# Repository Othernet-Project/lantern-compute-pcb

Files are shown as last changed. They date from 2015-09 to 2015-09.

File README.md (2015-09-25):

# lantern-compute-pcb
The files in this repo pertain to Lantern's main PCB. This includes the schematic, gerbers, and BOM, in addition to project outputs from Altrium 15. 

Lantern is a portable satellite data receiver which consists of a main compute board and separate RF module which receives satellite transmissions between 1525MHz and 1559MHz. 

V1 of the Lantern compute pcb is derived from the Beaglebone Black single board computer. The main differences between V1 and BBB include the addition of a DVB-S2 network interface module (NIM), as well as an onboard wifi module. Unlike the BBB, V1 does not provide for a video interface.

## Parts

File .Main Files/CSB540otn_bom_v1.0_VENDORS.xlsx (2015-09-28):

Comment | Description | Designator | Footprint | LibRef | Quantity | Vendor | Manufacturer | Mfg Part Number
22PF_50V, 0402 | CAP - 0402 PKG | C1, C2, C3, C4, C35, C36, C130, C140 | 0402C | 22PF_50V, 0402 | 8 | Digikey | KEMET | C0402C220J5GACTU
10UF_10V, 0805 | CAP - 0805 PKG | C5, C32, C47, C50, C56, C59, C61, C62, C116, C126, C128, C134, C155 | 0805C | 10UF_10V, 0805 | 13 | Digikey | TAIYO YUDEN | LMK212F106ZG-T
2.2UF_6V, 0402 | CAP - 0402 PKG | C6, C7, C8, C9, C10, C11, C12, C18, C23, C25, C26, C38, C51, C55, C67, C72, C77, C82, C87, C92, C97, C102, C112, C139, C141, C145, C147, C149, C150 | 0402C | 2.2UF_6V, 0402 | 29 | Digikey | TAIYO YUDEN | JMK105BJ225MV-F
0.1UF_16V, 0402 | CAP - 0402 PKG | C13, C14, C15, C16, C17, C19, C20, C21, C22, C24, C30, C31, C33, C37, C39, C40, C41, C42, C43, C52, C53, C54, C63, C64, C65, C66, C68, C69, C70, C71, C73, C74, C75, C76, C78, C79, C80, C81, C83, C84, C85, C86, C88, C89, C90, C91, C93, C94, C95, C96, C98, C99, C100, C101, C107, C108, C109, C110, C111, C122, C129, C142, C143, C144, C146, C148, C151, C152 | 0402C | 0.1UF_16V, 0402 | 68 | Digikey | TAIYO YUDEN | EMK105B7104KV-F
10UF_6V, 0603 | CAP - 0603 PKG | C27, C28, C124, C132 | 0603C | 10UF_6V, 0603 | 4 | Digikey | SAMSUNG | CL10A106MQ8NNNC
1000PF_2KV, 1206 | CAP - 1206 PKG | C29 | 1206C | 1000PF_2KV, 1206 | 1 | Digikey | KEMET | C1206C102KGRACTU
220UF_16V_POLY_8X8 | CAP - ELEC_POLY, 8mm x 8mm x 3.5mm | C34, C46, C58, C117, C118, C153 | ELEC_8MM_8MM | 220UF_16V_POLY_8X8 | 6 | Digikey | NICHICON | RL81C221MDN1KX
1UF_10V, 0402 | CAP - 0402 PKG | C44, C49, C103, C104, C105, C113, C114, C115, C123, C138, C154, C156 | 0402C | 1UF_10V, 0402 | 12 | Digikey | MURATA | GRM155R61A105KE15D
0PF_DNP, 0402 | CAP - 0402 PKG | C45, C57, C125, C131 | 0402C | 0PF_DNP, 0402 | 4
22UF_6V, 0805 | CAP - 0805 PKG | C48, C60, C121, C127, C133 | 0805C | 22UF_6V, 0805 | 5 | Digikey | TAIYO YUDEN | JMK212BJ226MG-T
.01UF_25V, 0402 | CAP - 0402 PKG | C106, C120 | 0402C | .01UF_25V, 0402 | 2 | Digikey | MURATA | GRM155R71E103KA01D
22UF_10V, 1206 | CAP - 1206 PKG | C119 | 1206C | 22UF_10V, 1206 | 1 | Digikey | TAIYO YUDEN | LMK316F226ZL-T
22UF_25V, 1210 | CAP - 1210 PKG | C135 | 1210C | 22UF_25V, 1210 | 1 | Digikey | TAIYO YUDEN | TMK325BJ226MM-T
220UF_35V, ELEC_8X11.5 | CAP - ELEC, 8mm x 11.5mm x 3.5mm | C136 | ELEC_8MM_11.5MM | 220UF_35V, ELEC_8X11.5 | 1 | Digikey | NICHICON | UVY1V221MPD
2200PF_50V, 0402 | CAP - 0402 PKG | C137 | 0402C | 2200PF_50V, 0402 | 1 | Digikey | TAIYO YUDEN | UMK105B7222KV-F
LED_1X3_SIDE-YELLOW | LED - SIDEVIEW, SMT, YELLOW | D1, D18 | LED_1X3_SIDE-YELLOW | LED_1X3_SIDE-YELLOW | 2 | Digikey | KINGBRIGHT | APA3010SYCK-GX
SEMTECH_RCLAMP0524PA | DIODE - TVS ARRAY, 0.3PF | D2, D10 | RCLAMP0524 | SEMTECH_RCLAMP0524PA | 2 | Digikey | SEMTECH | RCLAMP0524PATCT
LED_1X3_SIDE-GREEN | LED - SIDEVIEW, SMT, GREEN | D3, D7, D8 | LED_1X3_SIDE-GREEN | LED_1X3_SIDE-GREEN | 3 | Digikey | LITE-ON | LTST-S326KGJSKT
BAT54C, SOT-23 | DIODE - DUAL SCHOTTKY, COMMON CATHODE, 30V, 200MA | D4, D9 | SOT-23 | BAT54C, SOT-23 | 2 | Digikey | DIODES INC | BAT54C-7-F
BAT60, SOD-323 | DIODE - POWER, SCHOTTKY, 10V, 3A | D5 | SOD-323 | BAT60, SOD-323 | 1 | Digikey | ST Micro | BAT60JFILM
V10PN50, SOT-277 | DIODE - SCHOTTKY, 50V, 10A | D6 | SOT-277 | V10PN50, SOT-277 | 1 | Digikey | VISHAY | V10PN50-M3/86A
LED_1X3_SIDE-RED | LED - SIDEVIEW, SMT, RED | D11 | LED_1X3_SIDE-RED | LED_1X3_SIDE-RED | 1 | Digikey | KINGBRIGHT | APA3010SRCPRV-GX
LED_1X3_SIDE-WHITE | LED - SIDEVIEW, SMT, WHITE | D17 | LED_1X3_SIDE-WHITE | LED_1X3_SIDE-WHITE | 1 | Digikey | DIALIGHT | 5972903507F
MBRA340, SMA | DIODE - POWER, SCHOTTKY, 40V, 3A | D20 | SMA | MBRA340, SMA | 1 | Digikey | ON SEMI | MBRA340T3G
BAT54T, SOT-523 | DIODE - SCHOTTKY, 30V, 200MA | D21 | SOT-523 | BAT54T, SOT-523 | 1 | Digikey | DIODES INC | BAT54T-7-F
FIDUCIAL | MISC - 75mm/35mm FIDUCIAL | FID1, FID2 | FIDUCIAL | FIDUCIAL | 2
CUI_PJ-037BH | CONN - DC JACK, 2.5mm CENTER PLUS, 5 AMP | J1 | CUI_PJ-037B | CUI_PJ-037BH | 1 | Digikey | CUI INC | PJ-037B
SRP4020-1R0M | INDUCTOR - 1.0UH, 5/6A, 4MM x 4MM x 2MM, 22mohm | L2, L4, L10, L11, L17, L18 | SRP4020 | SRP4020-1R0M | 6 | Digikey | BOURNS | SRP4020-1R0M
FERRITE_600, 0402 | FERRITE BEAD - 600 OHM, 300MA, 0402 PKG | L5, L6, L7 | 0402L | FERRITE_600, 0402 | 3 | Digikey | TAIYO YUDEN | BK1005HS601-T
MURATA_DLP11TB800UL2 | FERRITE - COMMON MODE FILTER, USB3, FILM | L8, L19, L20 | PANASONIC_EXC24C | MURATA_DLP11TB800UL2 | 3 | Digikey | MURATA | DLP11TB800UL2L
FERRITE_600, 0805 | FERRITE BEAD - 600 OHM, 2A, 0805 PKG | L9, L13, L14, L15, L16, L23 | 0805L | FERRITE_600, 0805 | 6 | Digikey | TDK CORP | MMZ2012R601A
MURATA_DLP11SA900HL2 | FERRITE - COMMON MODE FILTER, USB2/HDMI/GIGe, FILM | L12 | PANASONIC_EXC24C | MURATA_DLP11SA900HL2 | 1 | Digikey | MURATA | DLP11SA900HL2L
NRS5020T-100M | INDUCTOR - 10UH, 1.3A/1.45A, 5MM x 5MM x 2MM | L22 | NRS5020T | NRS5020T-100M | 1 | Digikey | TAIYO YUDEN | NRS5020T100MMGJ
MTG_M2.5_UNPLATED | MTG HOLE - 2.75mm HOLE 2-56 OR M2.5 | M1, M2, M3, M4 | MTG_M2.5_UNPLATED | MTG_M2.5_UNPLATED | 4
HANRUN_HR851150H | CONN - RJ45 10/100 W/POE, SPEEDTECH | P1 | SPEEDTECH_P65-101-1HQ9 | HANRUN_HR851150H | 1 | HANRUN | HANRUN | HR851150H
USB-A-SMT | CONN - USB TYPE A SMT | P2 | USB-A-SMT | USB-A-SMT | 1 | Digikey | FCI | 87583-2010BLF
USB-MICRO-B | CONN - USB TYPE B MICRO | P3 | USB-MICRO-B | USB-MICRO-B | 1 | Digikey | FCI | 10118193-0001lf
USB-A-DUAL | CONN - USB TYPE A - DUAL | P4 | USB-A-DUAL | USB-A-DUAL | 1 | Digikey | FCI | 72309-8034BLF
HDR2 - NOPOP | HEADER - 2-PIN, HOLES ONLY FOR WIRE | P5, P7 | HDR2X1-NOPOP | HDR2 - NOPOP | 2
ARM-ICE, HDR20 | CONN - ARM JTAG CONNECTOR | P6 | HDR20 | ARM-ICE, HDR20 | 1 | Digikey | ON SHORE TECH | 302-S201
2N7002T, SOT-523 | N-FET - 60V, 500ma @ 10V, Vgs(th) 2V | Q1, Q3, Q5 | SOT-523 | 2N7002T, SOT-523 | 3 | Digikey | DIODES INC | 2N7002T-7-F
FDMA910PZ, MICROFET-22 | P-FET - 20V, 7.2A @ 1.8Vgs, 34mohm | Q2, Q4 | MICROFET-22 | FDMA910PZ, MICROFET-22 | 2 | Digikey | FAIRCHILD SEMI | FDMA910PZ
2N7002V, SOT-563 | N-FET - DUAL, 60V, 500ma @ 10V, Vgs(th) 2V | Q6 | SOT-563 | 2N7002V, SOT-563 | 1 | Digikey | DIODES INC | 2N7002V-7
1K, 0402 | RES - 0402 PKG | R1, R6, R46, R47, R48, R53, R56 | 0402R | 1K, 0402 | 7 | Digikey | VISHAY | CRCW04021K00JNED
2.2K, 0402 | RES - 0402 PKG | R2, R54 | 0402R | 2.2K, 0402 | 2 | Digikey | VISHAY | CRCW04022K20JNED
10K, 0402 | RES - 0402 PKG | R3, R15, R16, R20, R23, R24, R30, R31, R38, R42, R52, R57, R58, R60, R61 | 0402R | 10K, 0402 | 15 | Digikey | VISHAY | CRCW040210K0JNED
49.9_1%, 0402 | RES - 0402 PKG | R4 | 0402R | 49.9_1%, 0402 | 1 | Digikey | VISHAY | CRCW040249R9FKED
240, 0402 | RES - 0402 PKG | R5 | 0402R | 240, 0402 | 1 | Digikey | VISHAY | CRCW0402240RJNED
33, 0402 | RES - 0402 PKG | R7, R8, R32, R50 | 0402R | 33, 0402 | 4 | Digikey | VISHAY | CRCW040233R0JNED
1.00K_1%, 0402 | RES - 0402 PKG | R9, R10, R65 | 0402R | 1.00K_1%, 0402 | 3 | Digikey | VISHAY | CRCW04021K00FKED
12.1K_1%, 0402 | RES - 0402 PKG | R11 | 0402R | 12.1K_1%, 0402 | 1 | Digikey | VISHAY | CRCW040212K1FKED
10.0K_1%, 0402 | RES - 0402 PKG | R12, R29, R37, R41, R44, R59 | 0402R | 10.0K_1%, 0402 | 6 | Digikey | VISHAY | CRCW040210K0FKED
75, 0402 | RES - 0402 PKG | R13, R27, R35, R49 | 0402R | 75, 0402 | 4 | Digikey | VISHAY | CRCW040275R0JNED
1M, 0402 | RES - 0402 PKG | R14, R34 | 0402R | 1M, 0402 | 2 | Digikey | VISHAY | CRCW04021M00JNED
330, 0402 | RES - 0402 PKG | R17, R18, R19 | 0402R | 330, 0402 | 3 | Digikey | VISHAY | CRCW0402330RFKED
475K_1%, 0402 | RES - 0402 PKG | R21 | 0402R | 475K_1%, 0402 | 1 | Digikey | VISHAY | CRCW0402475KFKED
1.1K, 0402 | RES - 0402 PKG | R22 | 0402R | 1.1K, 0402 | 1 | Digikey | VISHAY | CRCW04021K10JNED
16.9K_1%, 0402 | RES - 0402 PKG | R25 | 0402R | 16.9K_1%, 0402 | 1 | Digikey | VISHAY | CRCW040216K9FKED
0_DNP, 0402 | RES - 0402 PKG, DO NOT POPULATE BY DEFAULT | R26, R33, R39, R43 | 0402R | 0_DNP, 0402 | 4
12.7K_1%, 0402 | RES - 0402 PKG | R28 | 0402R | 12.7K_1%, 0402 | 1 | Digikey | VISHAY | CRCW040212K7FKED
31.6K_1%, 0402 | RES - 0402 PKG | R36 | 0402R | 31.6K_1%, 0402 | 1 | Digikey | VISHAY | CRCW040231K6FKED
3.92K_1%, 0402 | RES - 0402 PKG | R40 | 0402R | 3.92K_1%, 0402 | 1 | Digikey | VISHAY | CRCW04023K92FKED
14.3K_1%, 0402 | RES - 0402 PKG | R45 | 0402R | 14.3K_1%, 0402 | 1 | Digikey | VISHAY | CRCW040214K3FKED
100K, 0402 | RES - 0402 PKG | R51, R62, R63 | 0402R | 100K, 0402 | 3 | Digikey | VISHAY | CRCW0402100KJNED
12.0K_1%, 0402 | RES - 0402 PKG | R55 | 0402R | 12.0K_1%, 0402 | 1 | Digikey | VISHAY | CRCW040212K0FKED
2.67K_1%, 0402 | RES - 0402 PKG | R64 | 0402R | 2.67K_1%, 0402 | 1 | Digikey | VISHAY | CRCW04022K67FKED
10KNI, EXB-28V | RES NET, 4 INDIVIDUAL, EXB-28V | RN1, RN3, RN4, RN8, RN9, RN10, RN11, RN12, RN13, RN14, RN17, RN18, RN19, RN20 | EXB-28V | 10KNI, EXB-28V | 14 | Digikey | PANASONIC | EXB-28V103JX
36NI, EXB-28V | RES NET, 4 INDIVIDUAL, EXB-28V | RN2, RN5, RN6, RN7, RN15, RN16 | EXB-28V | 36NI, EXB-28V | 6 | Digikey | PANASONIC | EXB-28V360JX
MOLEX_104031-0811 | CONN - SD/MMC, MICRO, PUSH/PUSH, W/CD | SD1 | MOLEX_104031-0811 | MOLEX_104031-0811 | 1 | Digikey | MOLEX | 104031-0811
ALP_SKQM | SWITCH - PUSHBUTTON SMT, 6MM X 3.5MM | SW1, SW4 | ALPS_SKQM | ALP_SKQM | 2 | MOUSER | ALPS | SKQMASE010
KSS221G | SWITCH - PUSHBUTTON SMT, SIDE ACTUATED | SW2, SW3 | KSS221G | KSS221G | 2 | Digikey | C&K COMPONENTS | KSS221GLFS
DDR3_TESTPOINTS_X16 | MISC - DDR3 ROUTING PATTERN, 16-BIT | TP1 | DDR2-TP | DDR3_TESTPOINTS_X16 | 1
TP20R | MISC - TEST PAD, 20MIL ROUND | TP2, TP3 | TP_20R | TP20R | 2
SMAJ5CA, SMA | DIODE - TVS, 6.4V MIN., 7.25V MAX. | TVS1 | SMA | SMAJ5CA, SMA | 1 | Digikey | LITTELFUSE INC | SMAJ5.0CA
AM3358BZCZA100 | MPU - CORTEX-A8 CORE, SDIO, GIGe, USB x2, UART x3, CAN, 2D/3D | U1 | BGA324x18 | AM3358BZCZA100 | 1 | Digikey | TEXAS INSTRUMENTS | AM3358BZCZA100
AP2141, SOT-25-5 | IC - POWER SWITCH, 500MA, LOW TRUE | U3 | SOT-23-5 | AP2141, SOT-23-5 | 1 | Digikey | DIODES, INC | AP2141WG-7
MTFC4GACAANA-4M IT, TBGA100 | NAND FLASH - eMMC 4GB/8GB | U4 | TBGA100 | MTFC4GACAANA-4M IT, TBGA100 | 1 | ARROW | MICRON TECH | MTFC4GACAANA-4M IT
MT41K256M16HA-125M:E, BGA96 | SDRAM - 4GBIT, DDR3/L-1600, x16 | U5 | BGA96_DDR3_X16 | MT41K256M16HA-125M:E, BGA96 | 1 | ARROW | MICRON TECH | MT41K256M16HA-125:E
RT9040GQW, DFN10 | LDO - DDR2/3 VREF AND VTT, 3A | U7 | DFN10 | RT9040GQW, DFN10 | 1 | Digikey | RICHTEK USA | RT9040GQW
LAN8720A-CP, QFN24 | PHY - 10/100 RMII | U8 | QFN24 | LAN8720A-CP, QFN24 | 1 | Digikey | MICROCHIP TECH | LAN8720A-CP-TR
TPS3801E18DCK, SC-70-5 | IC - RESET, 1.71V, 200MSEC, MR INPUT, OPEN DRAIN OUTPUT | U9 | SOT-353/SC-70-5 | TPS3801E18DCK, SC-70-5 | 1 | Digikey | TEXAS INSTRUMENTS | TPS3801E18DCKR
FAN5354MPX, MLP12 | SWITCHER - 270ua Iq, 3A, 2.7V TO 5.5V IN, 0.8V TO VIN OUT | U11, U14, U18, U19, U20 | mlp12 | FAN5354MPX, MLP12 | 5 | Digikey | FAIRCHILD SEMI | FAN5354MPX
FSA832L10X, MICROPAK10 | USB - BATTERY CHARGER DETECTION W/SWITCH | U12 | MICROpack10 | FSA832L10X, MICROPAK10 | 1 | Digikey | FAIRCHILD SEMI | FSA832L10X
COSY_TS2M08-HF111 | RF - MODULE, DVB-S2 TUNER/DEMODULATOR | U13 | TS2M08-HFF11 | COSY_TS2M08-HF111 | 1 |  | COSY | TS2M08-HF111
TPS61232DRC, SON10 | SWITCHER - 500ua Iq, BOOST 5A, 2.3V TO 5.5V IN, 2.5V TO 5.5V OUT | U15 | SON10 | TPS61232DRC, SON10 | 1 | Digikey | TEXAS INSTRUMENTS | TPS61232DRCT
CP2104-F03-GM, QFN24 | USB - UART W/4 GPIO | U16 | QFN24 | CP2104-F03-GM, QFN24 | 1 | Digikey | SILICON LABS | CP2104-F03-GM
MCP73123-22S, DFN10 | IC - BATTERY CHARGER, 1 CELL LiFePO4, 1.1 AMAX | U17 | DFN10 | MCP73123-22S, DFN10 | 1 | Digikey | MICROCHIP TECH | MCP73123-22SI/MF
AP2141, SOT-43-5 | IC - POWER SWITCH, 500MA, LOW TRUE | U21 | SOT-23-5 | AP2141, SOT-23-5 | 1 | Digikey | DIODES, INC | AP2141WG-7
MIC94060, SC-70-6 | IC - POWER SWITCH, 1.7V - 5.5V @ 2A, HIGH TRUE | U22, U24, U24 | SOT-363/SC-70-6 | MIC94060, SC-70-6 | 3 | Digikey | MICREL, INC | MIC94060YC6 TR
OGEMRAY_GWF-3M08 | MODULE - WIFI, RALINK RT5370 802.11b/g/n | U23 | OGEMRAY_GWF-3M08-XX-T-2 | OGEMRAY_GWF-3M08 | 1 |  | OGEMRAY | GWF-3M08
USB2514BI-AEZG, QFN36 | USB - 2.0 HUB, FOUR PORT, I-TEMP | U25 | QFN36 | USB2514BI-AEZG, QFN36 | 1 | Digikey | MICROCHIP TECH | USB2514B-AEZC-TR
AP2141, SOT-23-5 | IC - POWER SWITCH, 500MA, LOW TRUE | U26 | SOT-23-5 | AP2141, SOT-23-5 | 1 | Digikey | DIODES, INC | AP2141WG-7
LTC4412, SOT-23-6 | IC - POWER SOURCE SELECTOR | U27 | SOT-23-6 | LTC4412, SOT-23-6 | 1 | Digikey | LINEAR TECH | LTC4412ES6#TRMPBF
LMR64010XMF, SOT-23-5 | SWITCHER - BOOST, 1ma Iq, 2.7V TO 14V IN, VIN TO 40V OUT | U28 | SOT-23-5 | LMR64010XMF, SOT-23-5 | 1 | Digikey | TEXAS INSTRUMENTS | LMR64010XMFE/NOPB
BH18PB1WHFV, SOT-553 | LDO - 4ua Iq, 150ma, 3.4V - 5.5V IN, 1.8V OUT, 600mv Vdrop | VR1 | SOT-553 | BH18PB1WHFV, SOT-553 | 1 | Digikey | ROHM | BH18PB1WHFV-TR
32.768KHZ-12, 1206 | CRYSTAL - SMT, 1206, 12.5PF, ABS07 PKG | X1 | 1206X | 32.768KHZ-12, 1206 | 1 | Digikey | ABRACON | ABS07-32.768KHZ-T
24MHZ, X3225 | CRYSTAL - SMT, 3.2MM x 2.5MM, ABM8 PKG | X2, X4 | X3225 | 24MHZ, X3225 | 2 | Digikey | ABRACON | ABM8-24.000MHZ-B2-T
25MHZ, X3225 | CRYSTAL - SMT, 3.2MM x 2.5MM, ABM8 PKG | X3 | X3225 | 25MHZ, X3225 | 1 | Digikey | ABRACON | ABM8-25.000MHZ-B2-T

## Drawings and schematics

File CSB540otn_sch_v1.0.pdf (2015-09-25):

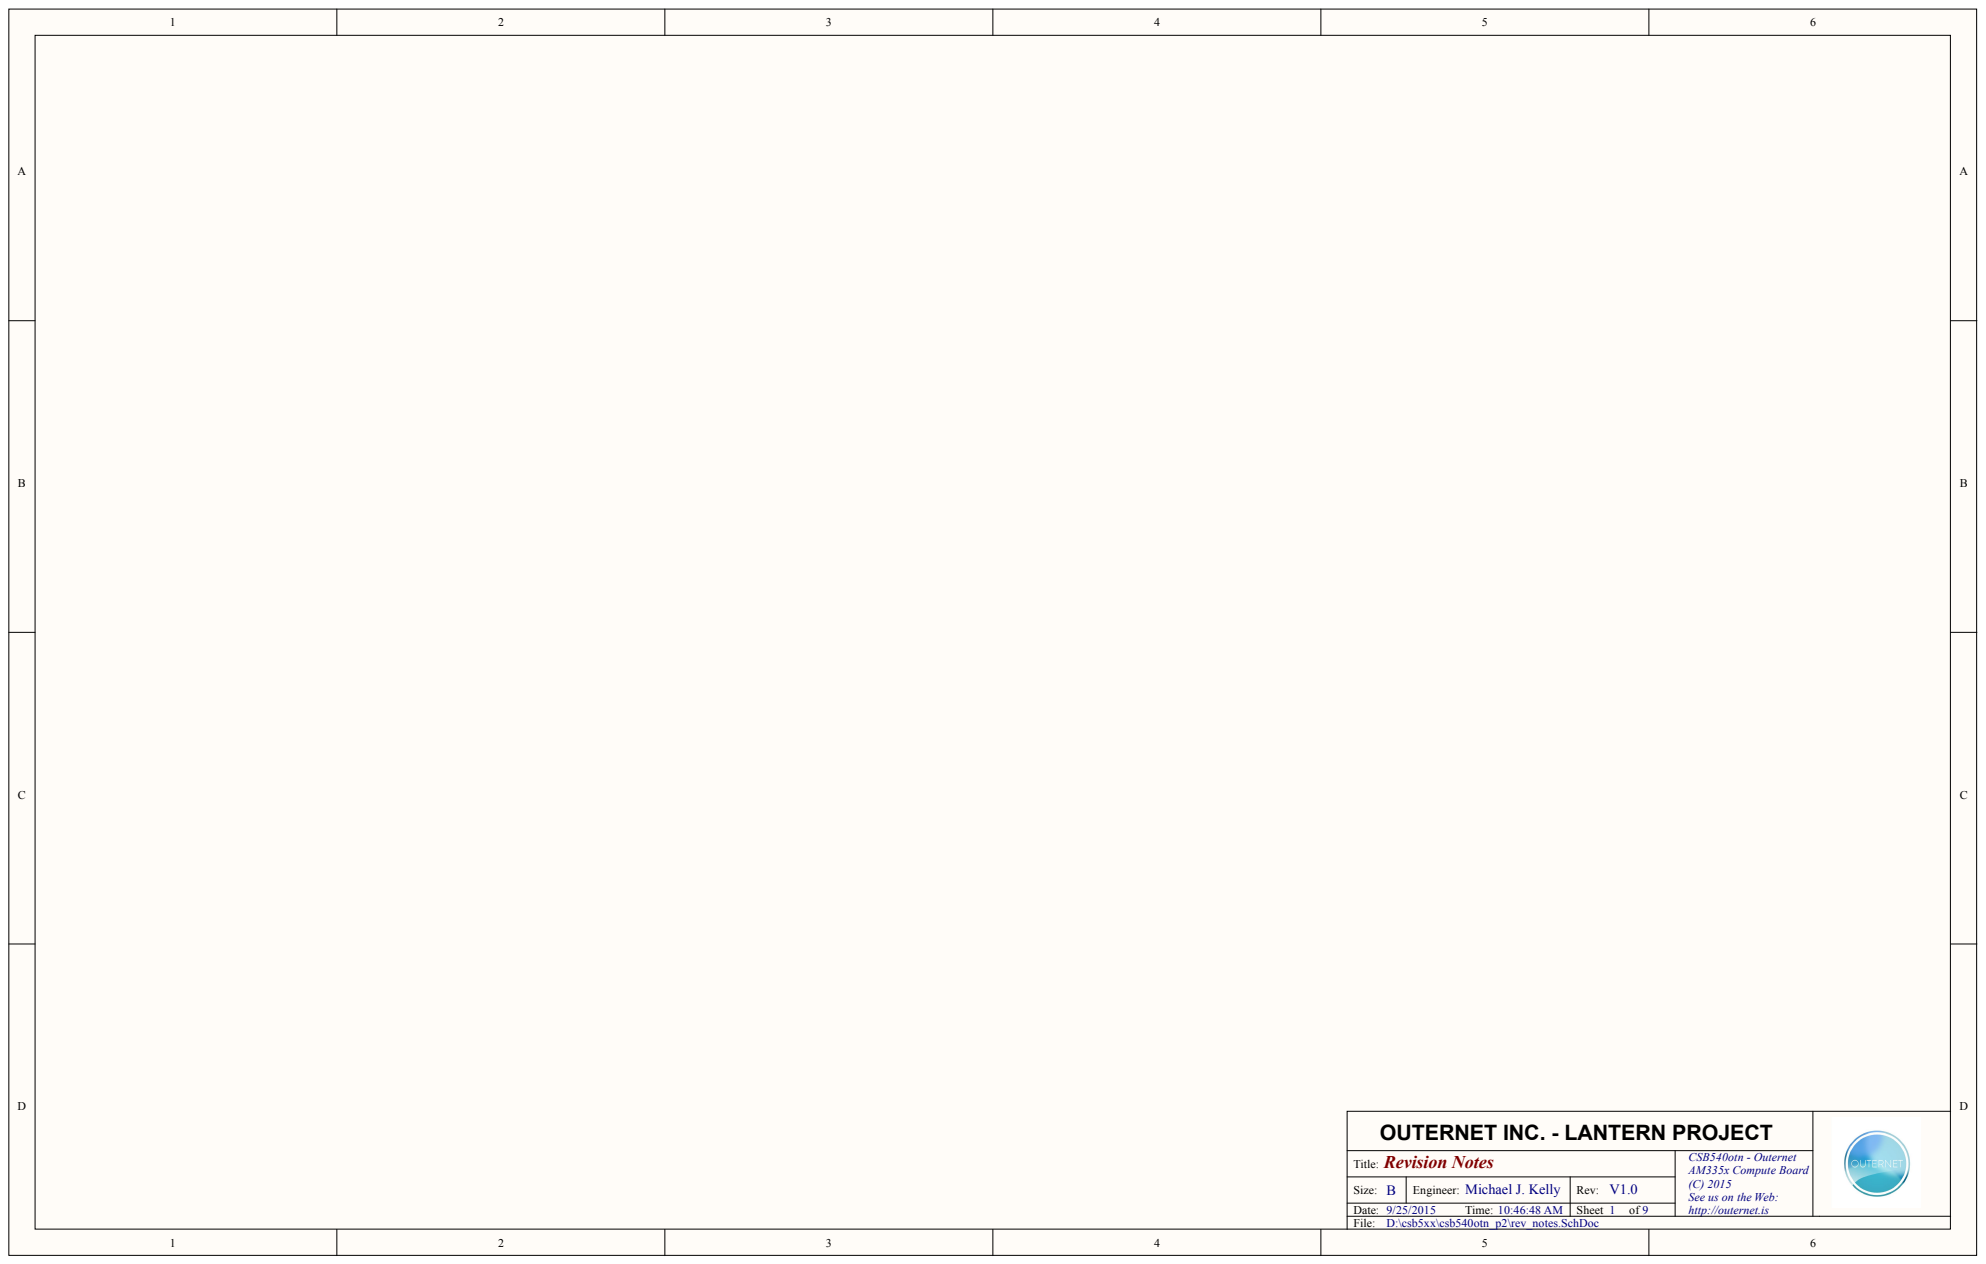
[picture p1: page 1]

OUTERNET INC. - LANTERN PROJECT

Title: Revision Notes | CSB540otn - Outernet AM335x Compute Board (C) 2015 See us on the Web: http://outernet.is

Size: B | Engineer: Michael J. Kelly | Rev: V1.0

Date: 9/25/2015 Time: 10:46:48 AM | | Sheet 1 of 9

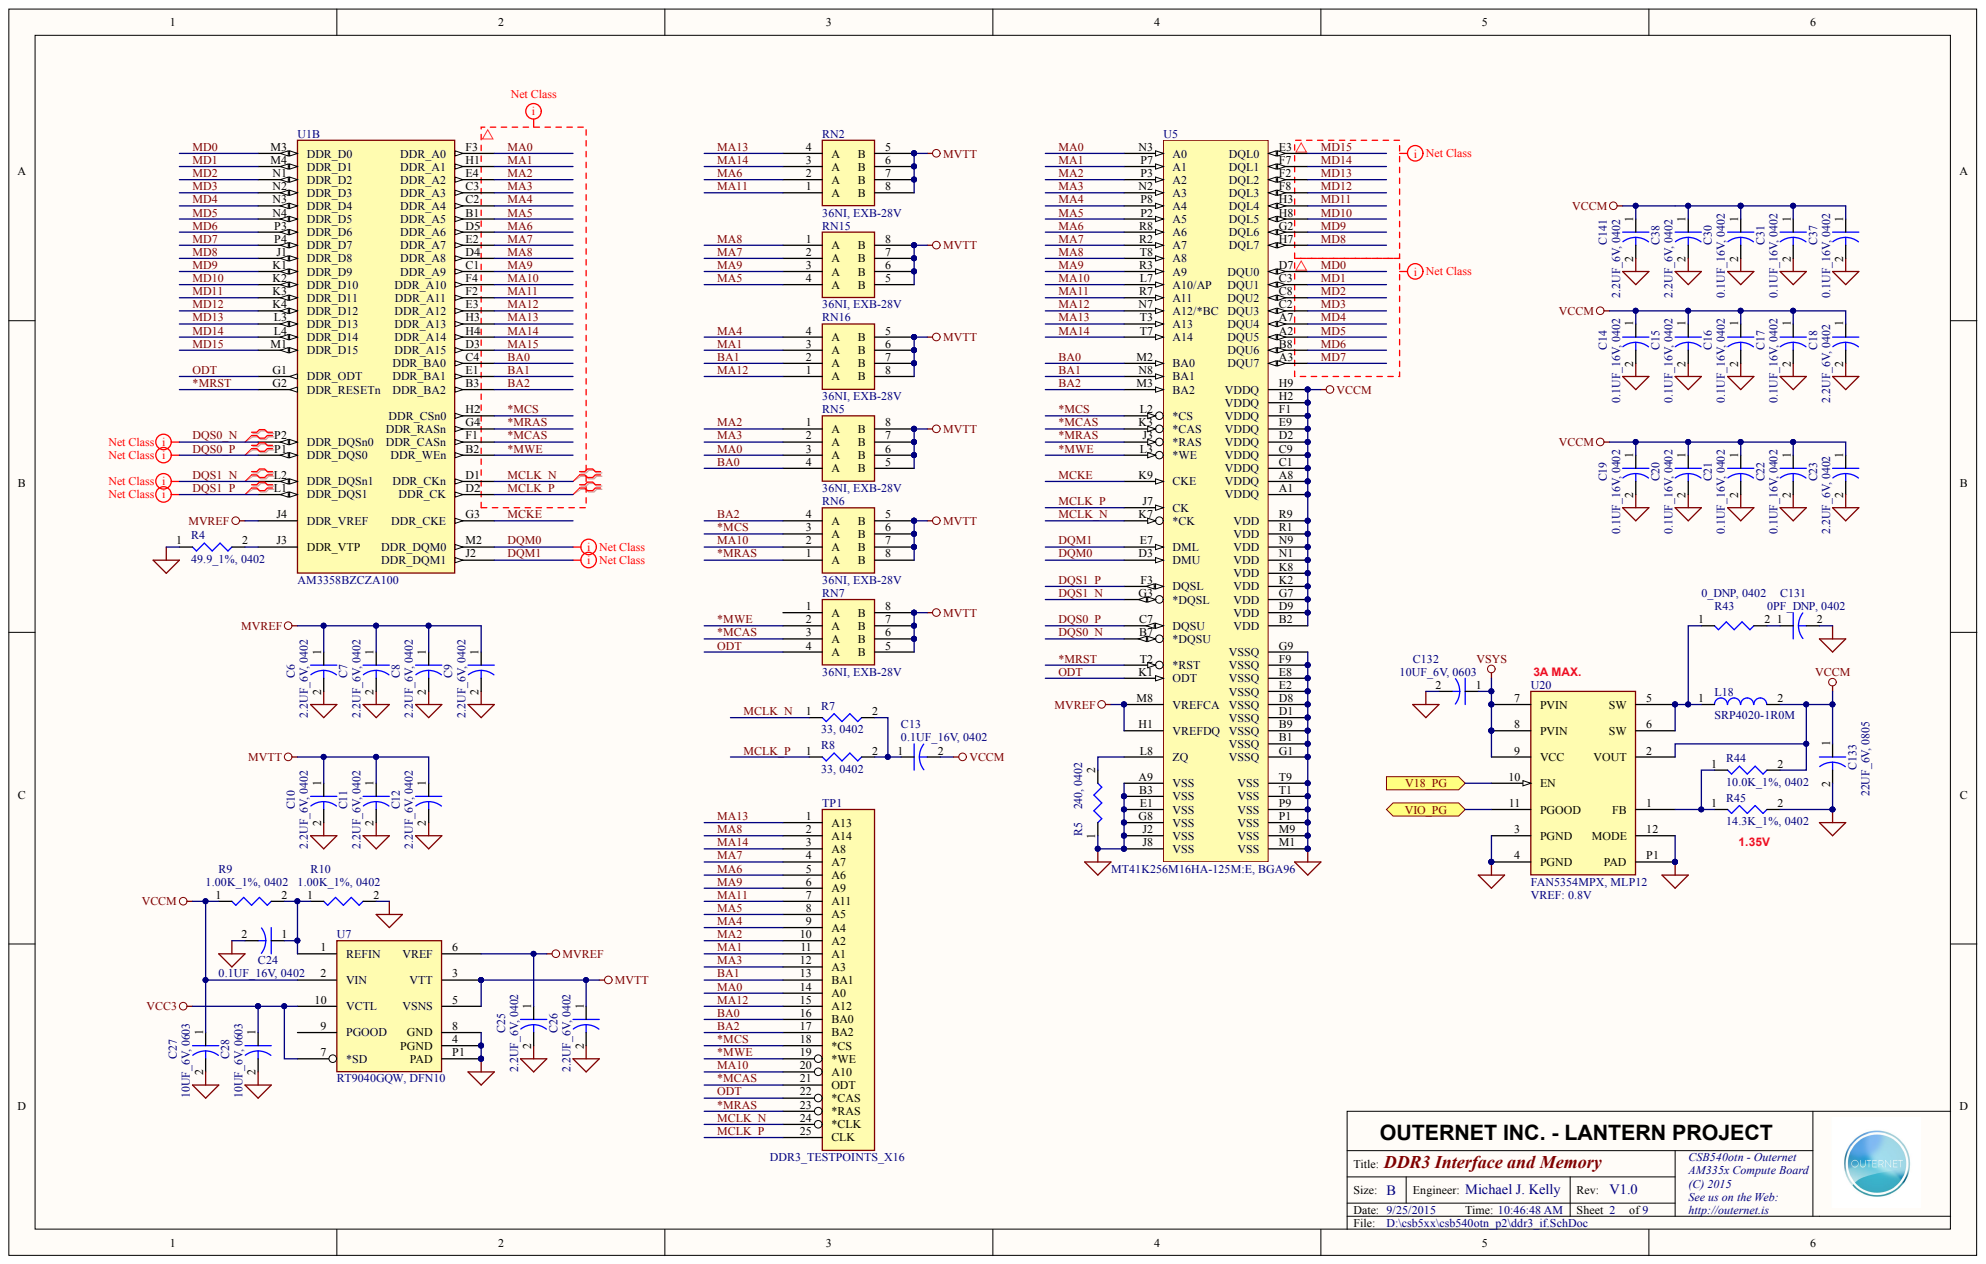
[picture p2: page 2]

i Net Class

OUTERNET INC. - LANTERN PROJECT

Size: B | En gineer: Michael J. Kelly | Rev : V1.0

Date: 9/2 5/2 0 1 5 Time: 1 0:4 6:4 8 AM | | Sheet 2 o f 9

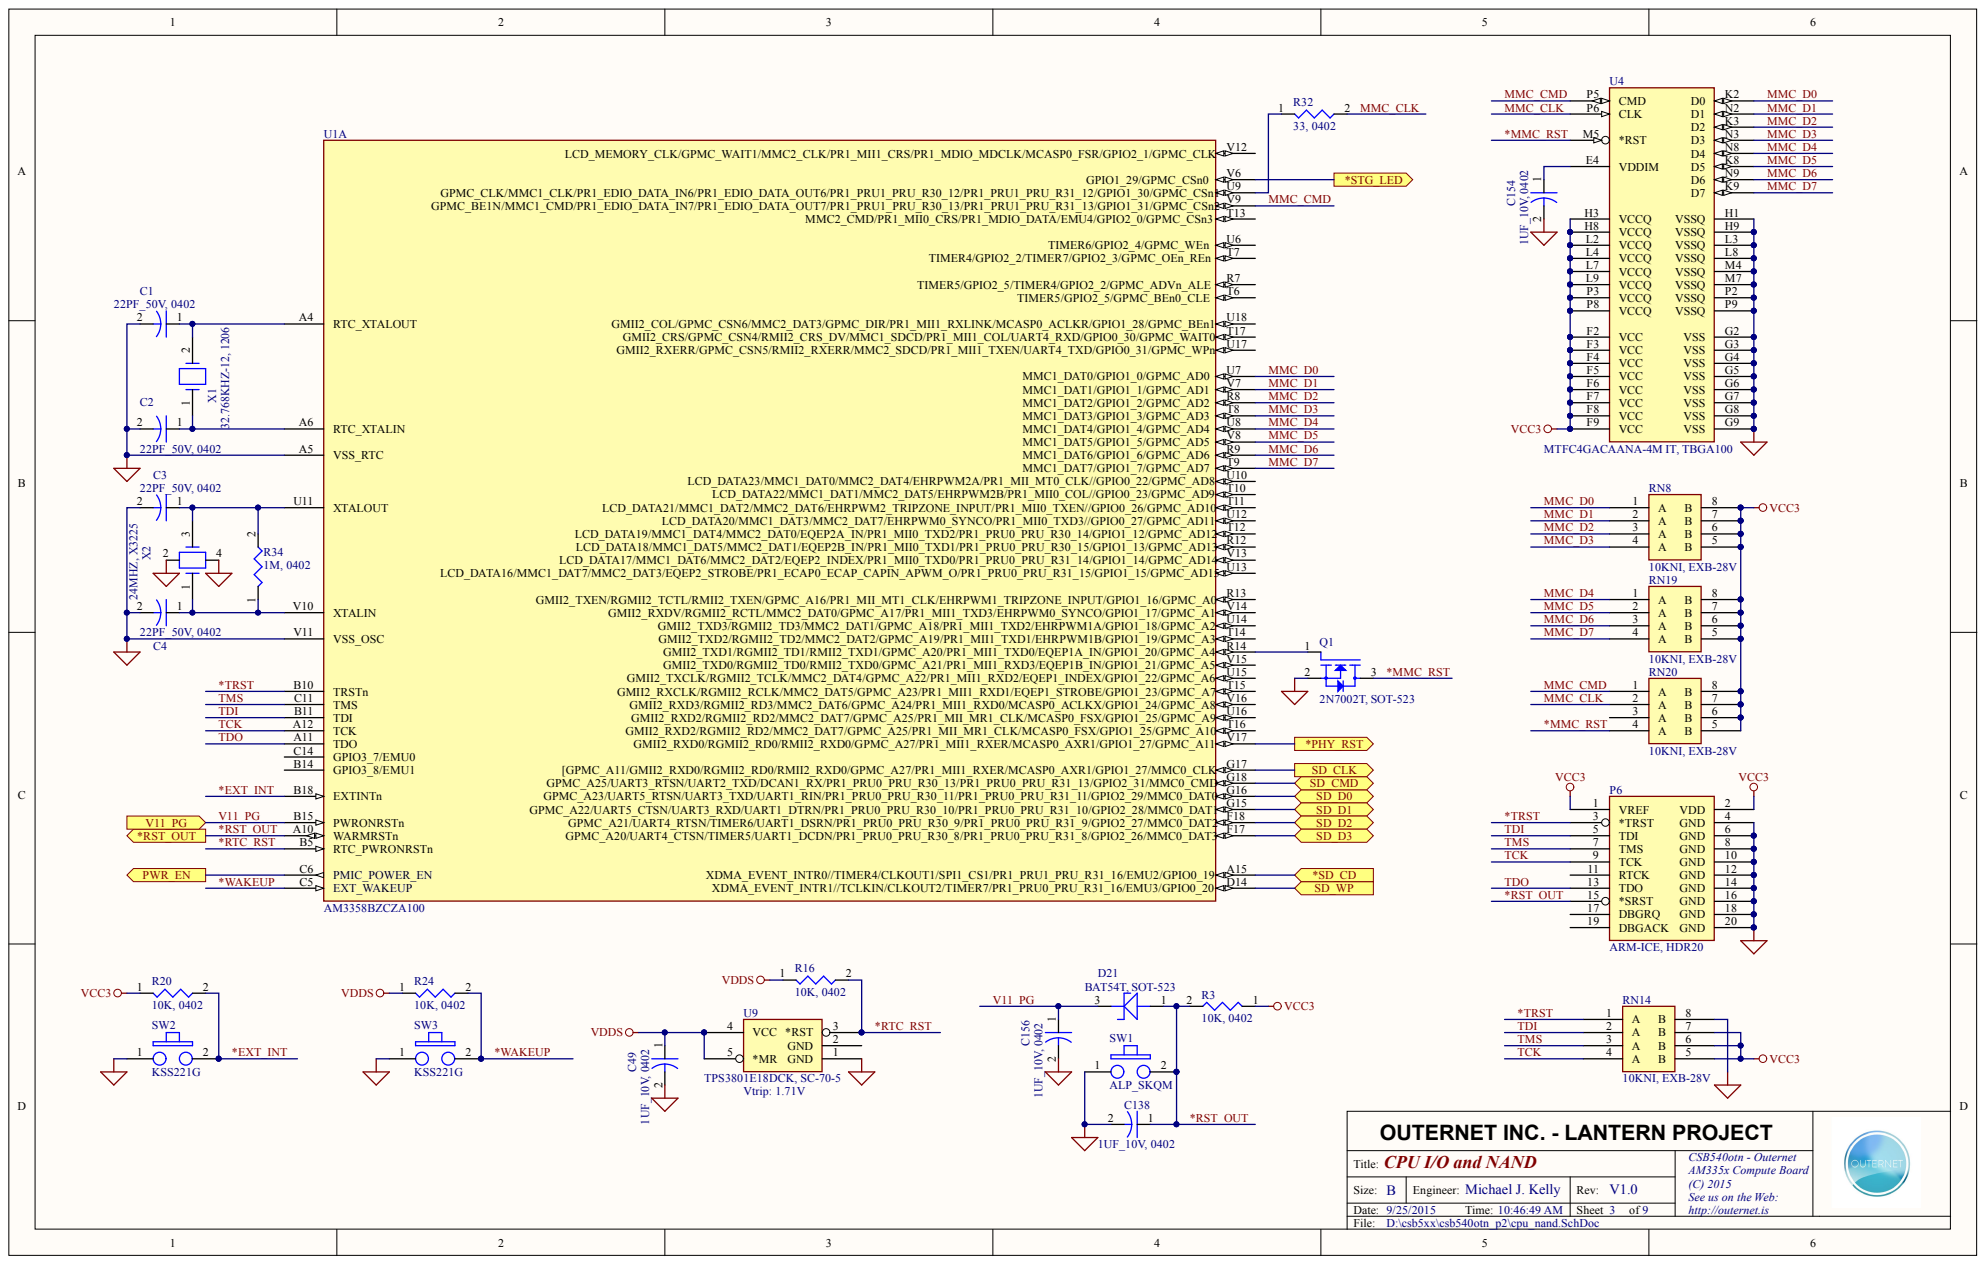
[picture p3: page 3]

OUTERNET INC. - LANTERN PROJECT

Title: CPU I/O and NAND | CSB540otn - Outernet AM335x Compute Board (C) 2015 See us on the Web: http://outernet.is

Size: B | Engineer: Michael J. Kelly | Rev: V1.0

Date: 9/25/2015 Time: 10:46:49 AM | | Sheet 3 of 9

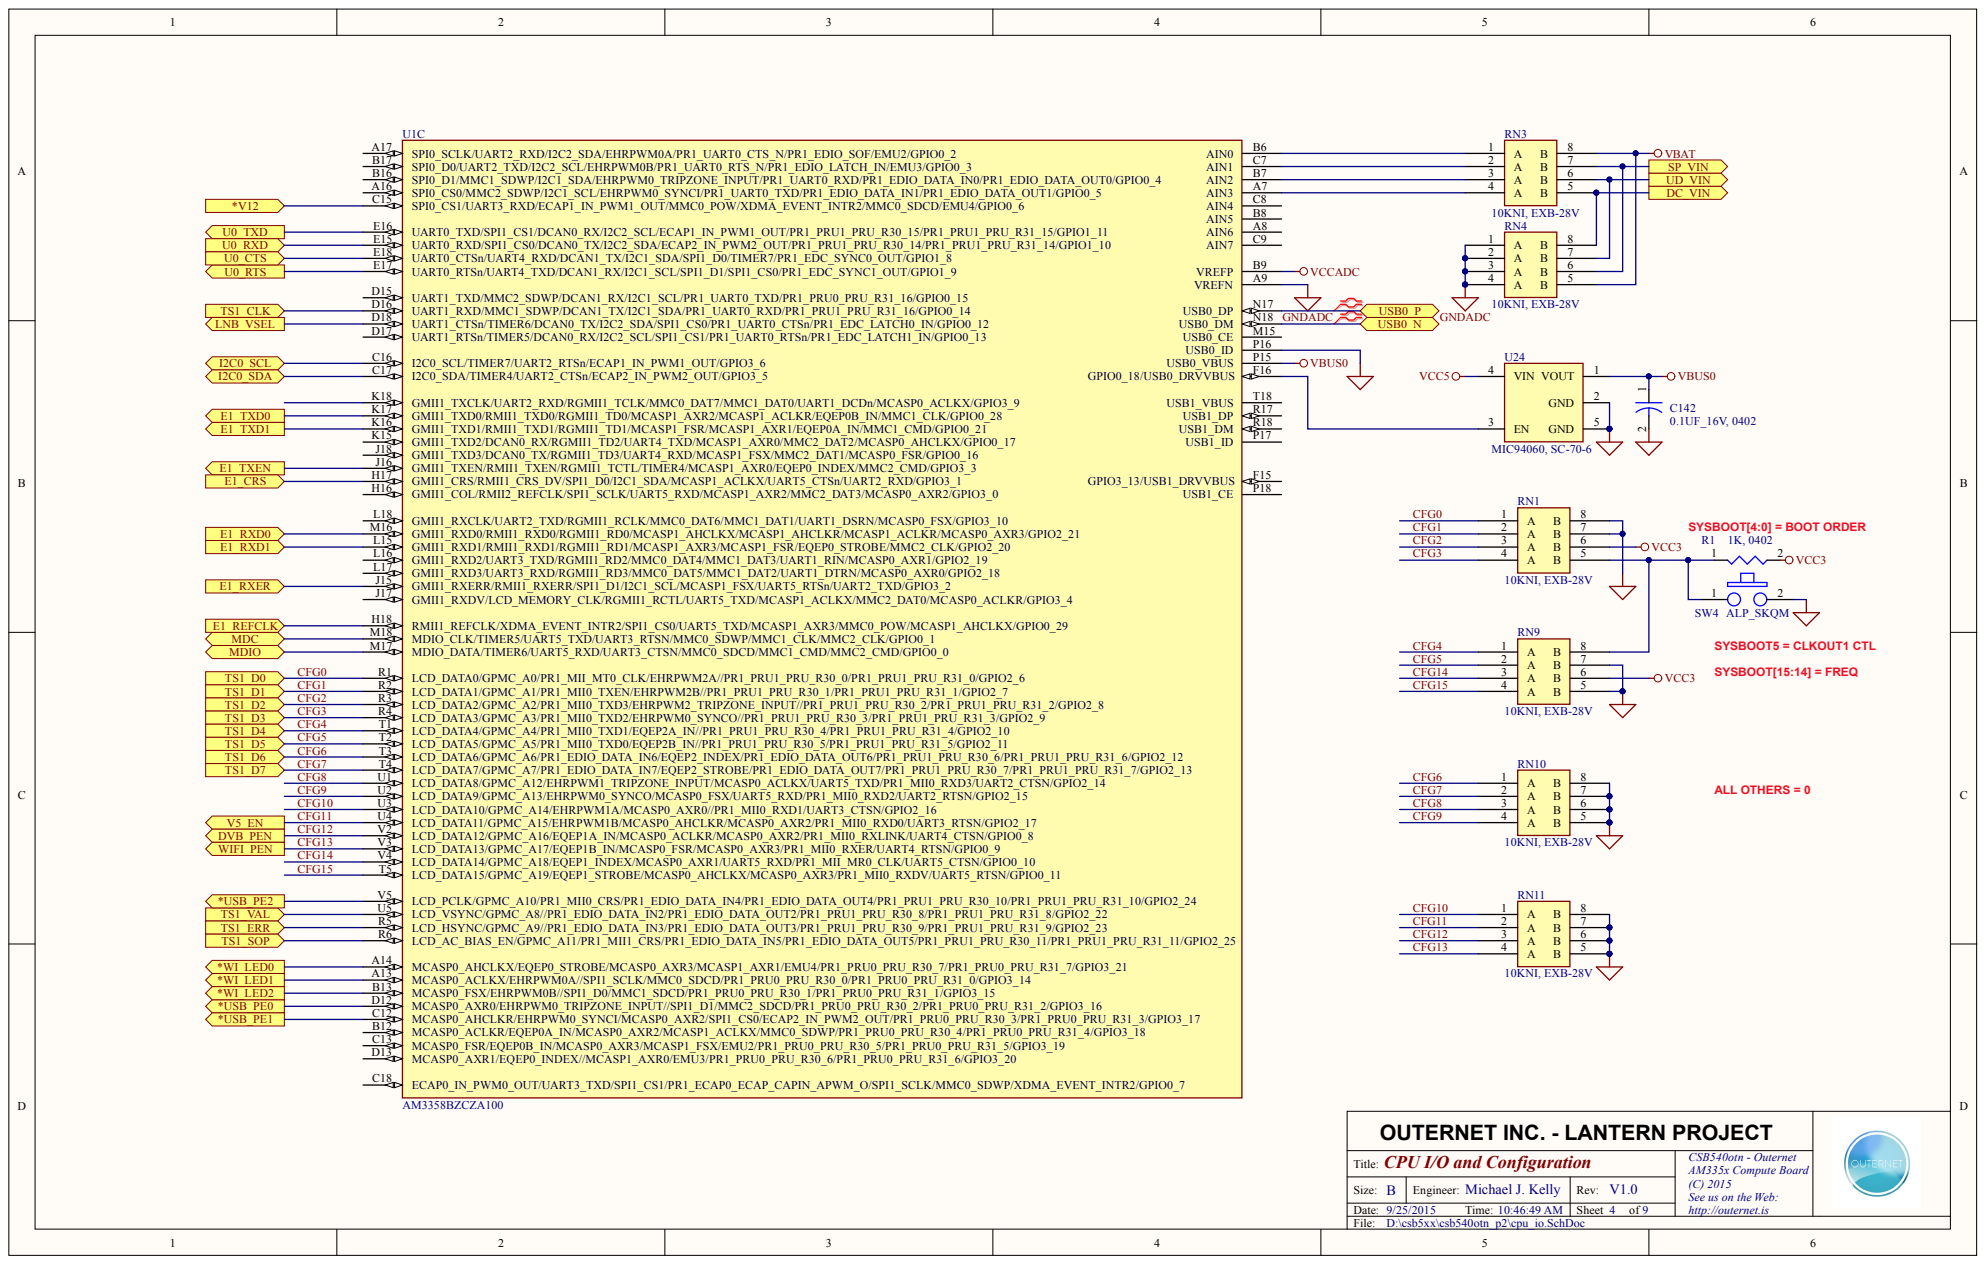
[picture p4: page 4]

1 8 V USB0 _ P USB0 _N

OUTERNET INC. - LANTERN PROJECT

Title: CPU I/O and Configuration | CSB5 4 0 otn - Outernet AM3 3 5x Comp ute Bo a rd (C) 2 0 1 5 See us o n the Web : http://o uternet.is

Size: B | En gineer: Michael J. Kelly | Rev : V1.0

Date: 9/2 5/2 0 1 5 Time: 1 0:4 6:4 9 AM | | Sheet 4 o f 9

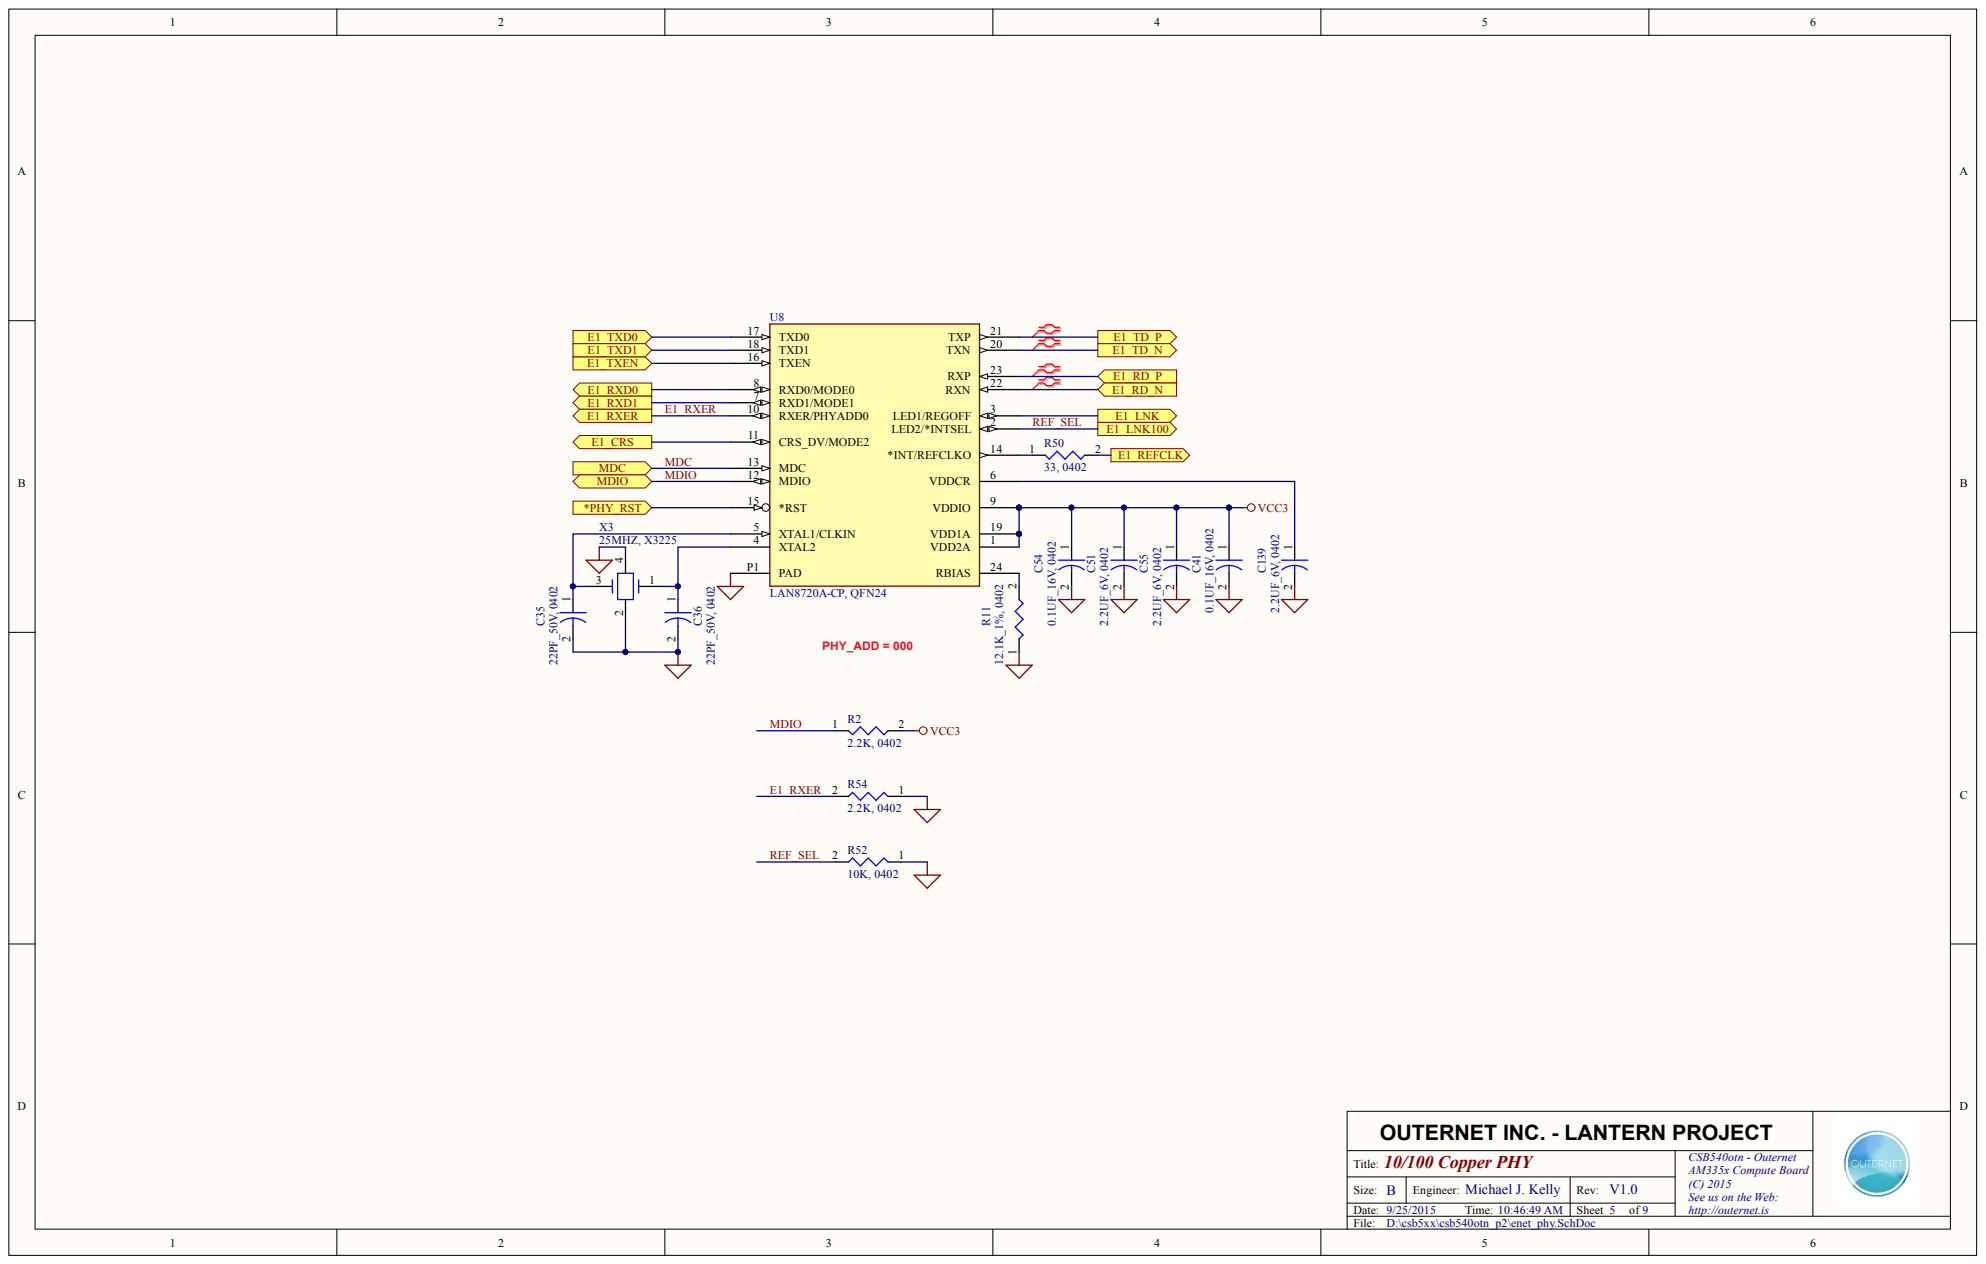
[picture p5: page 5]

OUTERNET INC. - LANTERN PROJECT

Title: 10/100 Copper PHY | CSB540otn - Outernet AM335x Compute Board (C) 2015 See us on the Web: http://outernet.is

Size: B | Engineer: Michael J. Kelly | Rev: V1.0

Date: 9/25/2015 Time: 10:46:49 AM | | Sheet 5 of 9

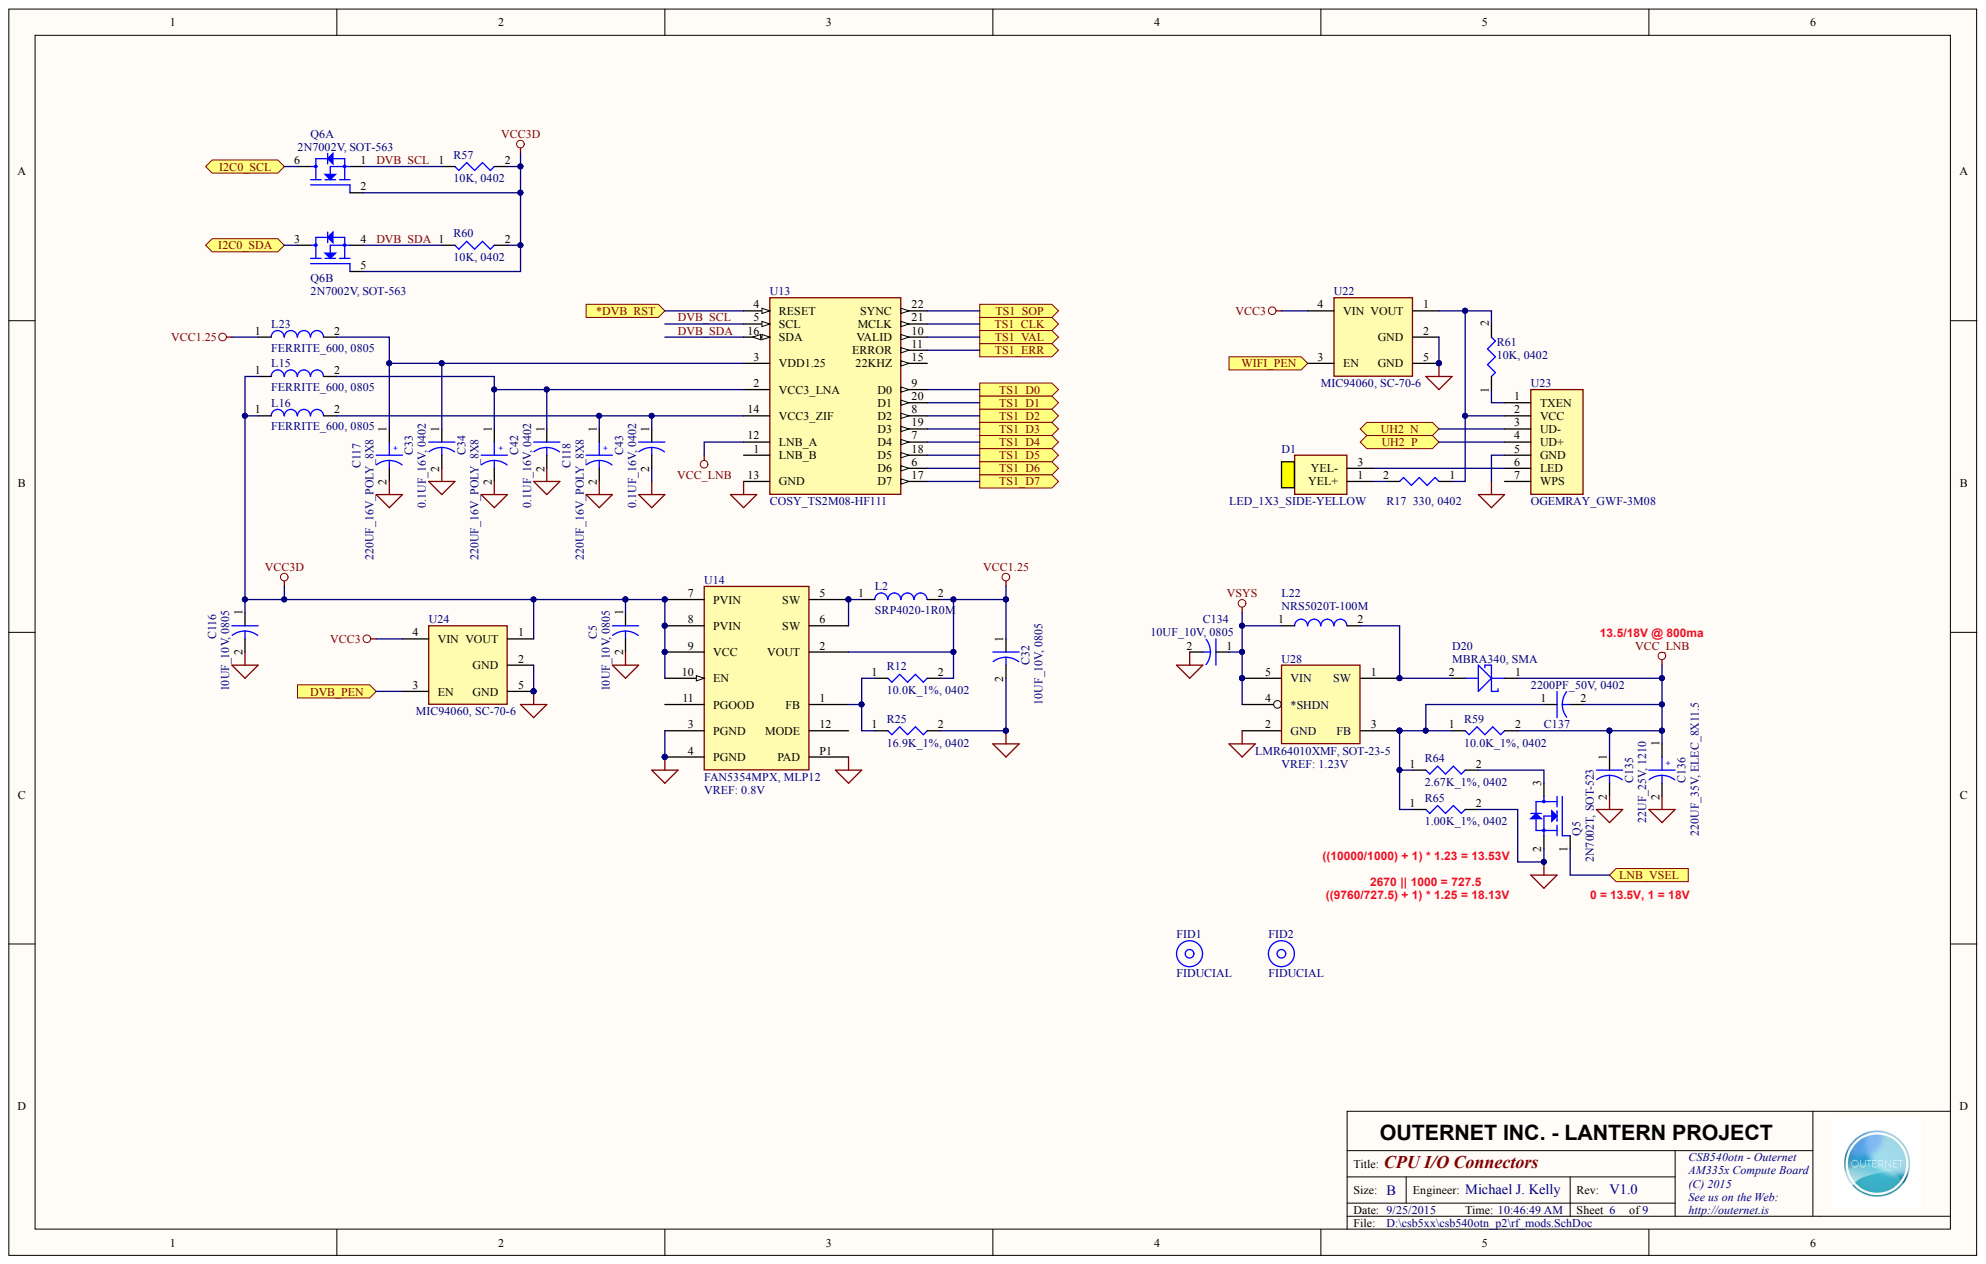
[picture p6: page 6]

OUTERNET INC. - LANTERN PROJECT

Title: CPU I/O Connectors | CSB540otn - Outernet AM335x Compute Board (C) 2015 See us on the Web: http://outernet.is

Size: B | Engineer: Michael J. Kelly | Rev: V1.0

Date: 9/25/2015 Time: 10:46:49 AM | | Sheet 6 of 9

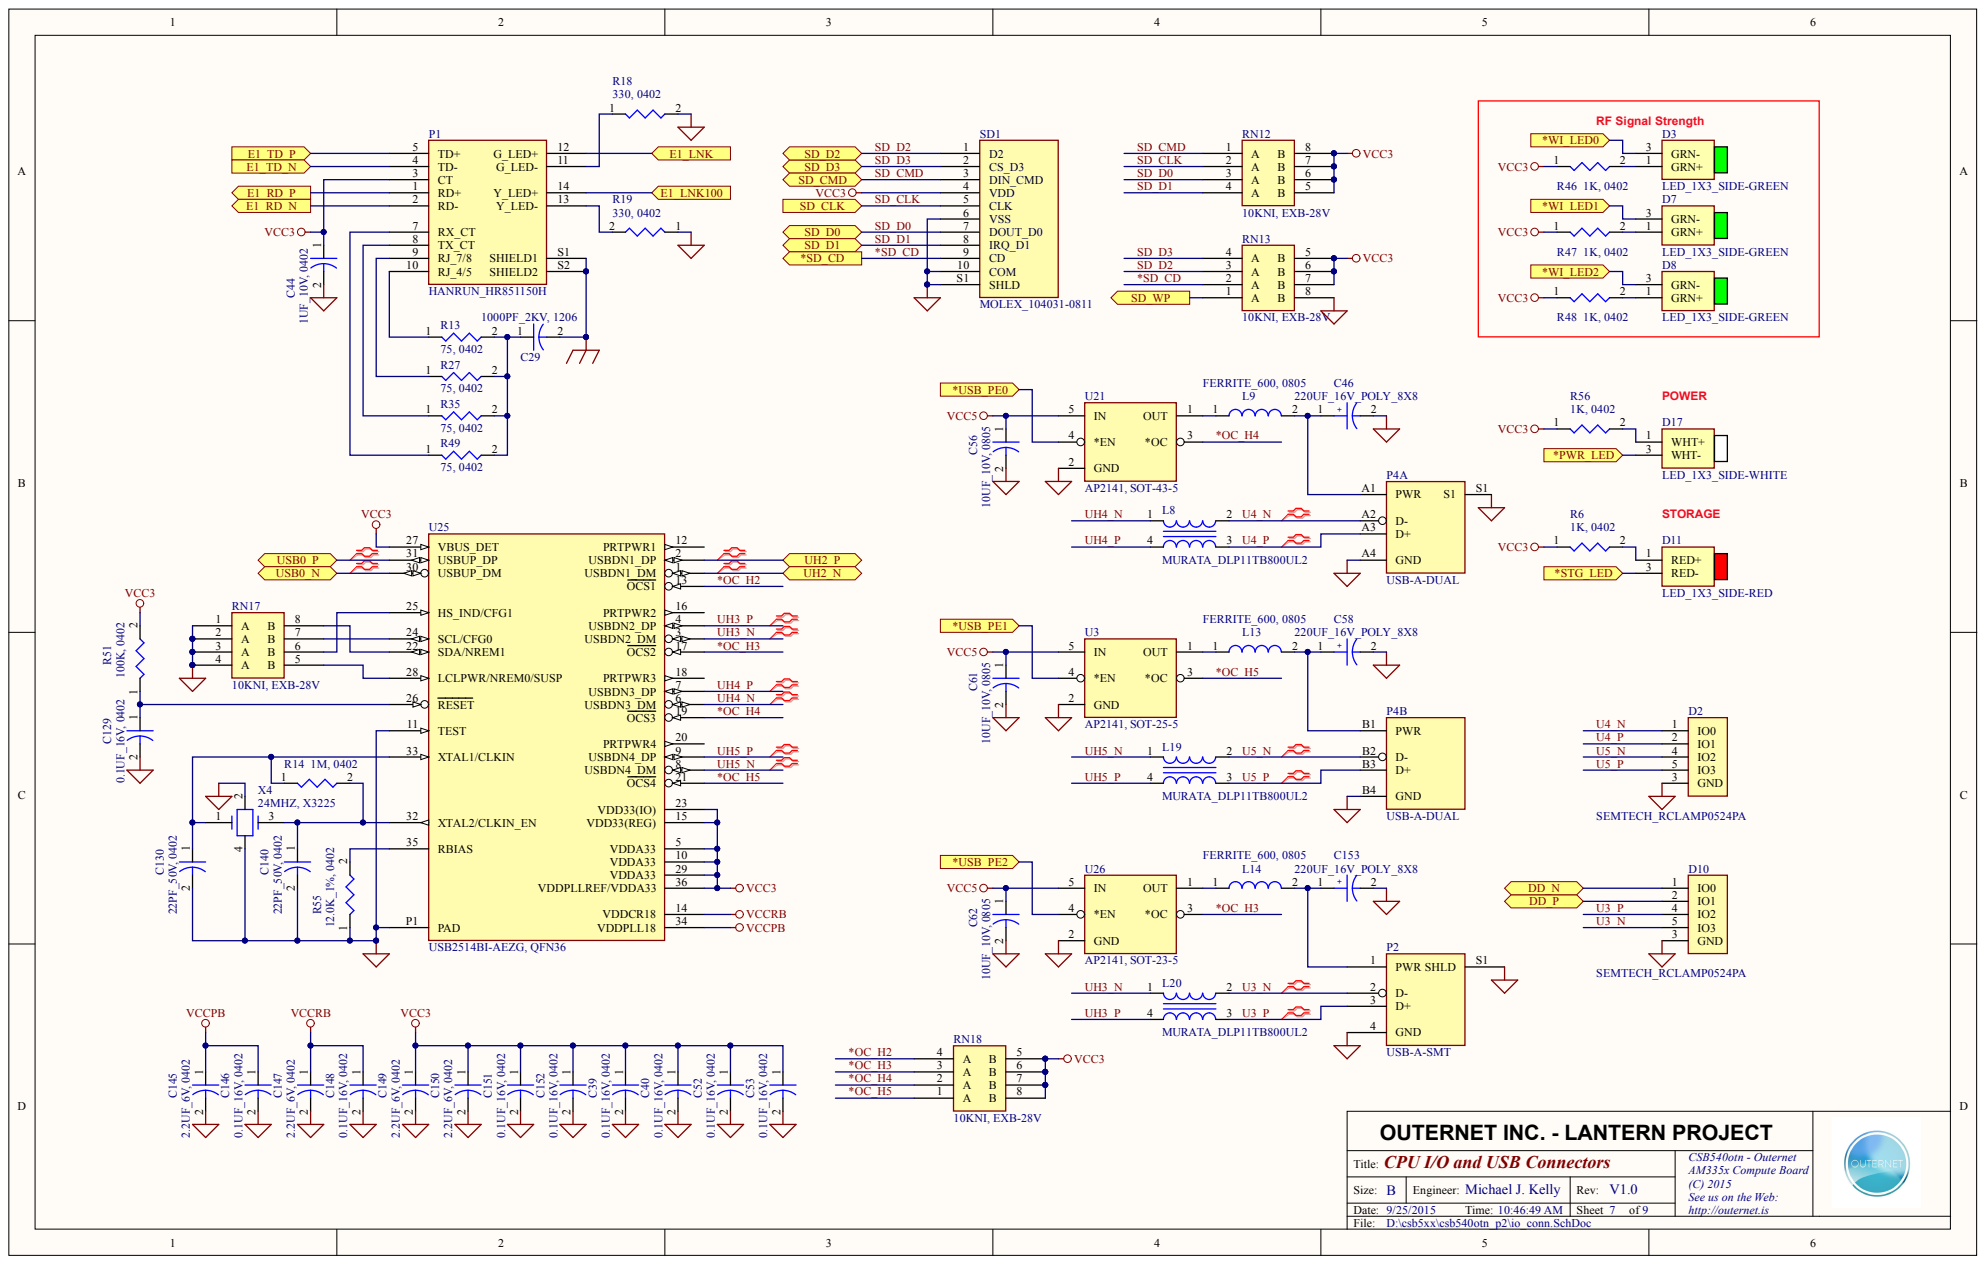
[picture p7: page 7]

OUTERNET INC. - LANTERN PROJECT

Title: CPU I/O and USB Connectors | CSB540otn - Outernet AM335x Compute Board (C) 2015 See us on the Web: http://outernet.is

Size: B | Engineer: Michael J. Kelly | Rev: V1.0

Date: 9/25/2015 Time: 10:46:49 AM | | Sheet 7 of 9

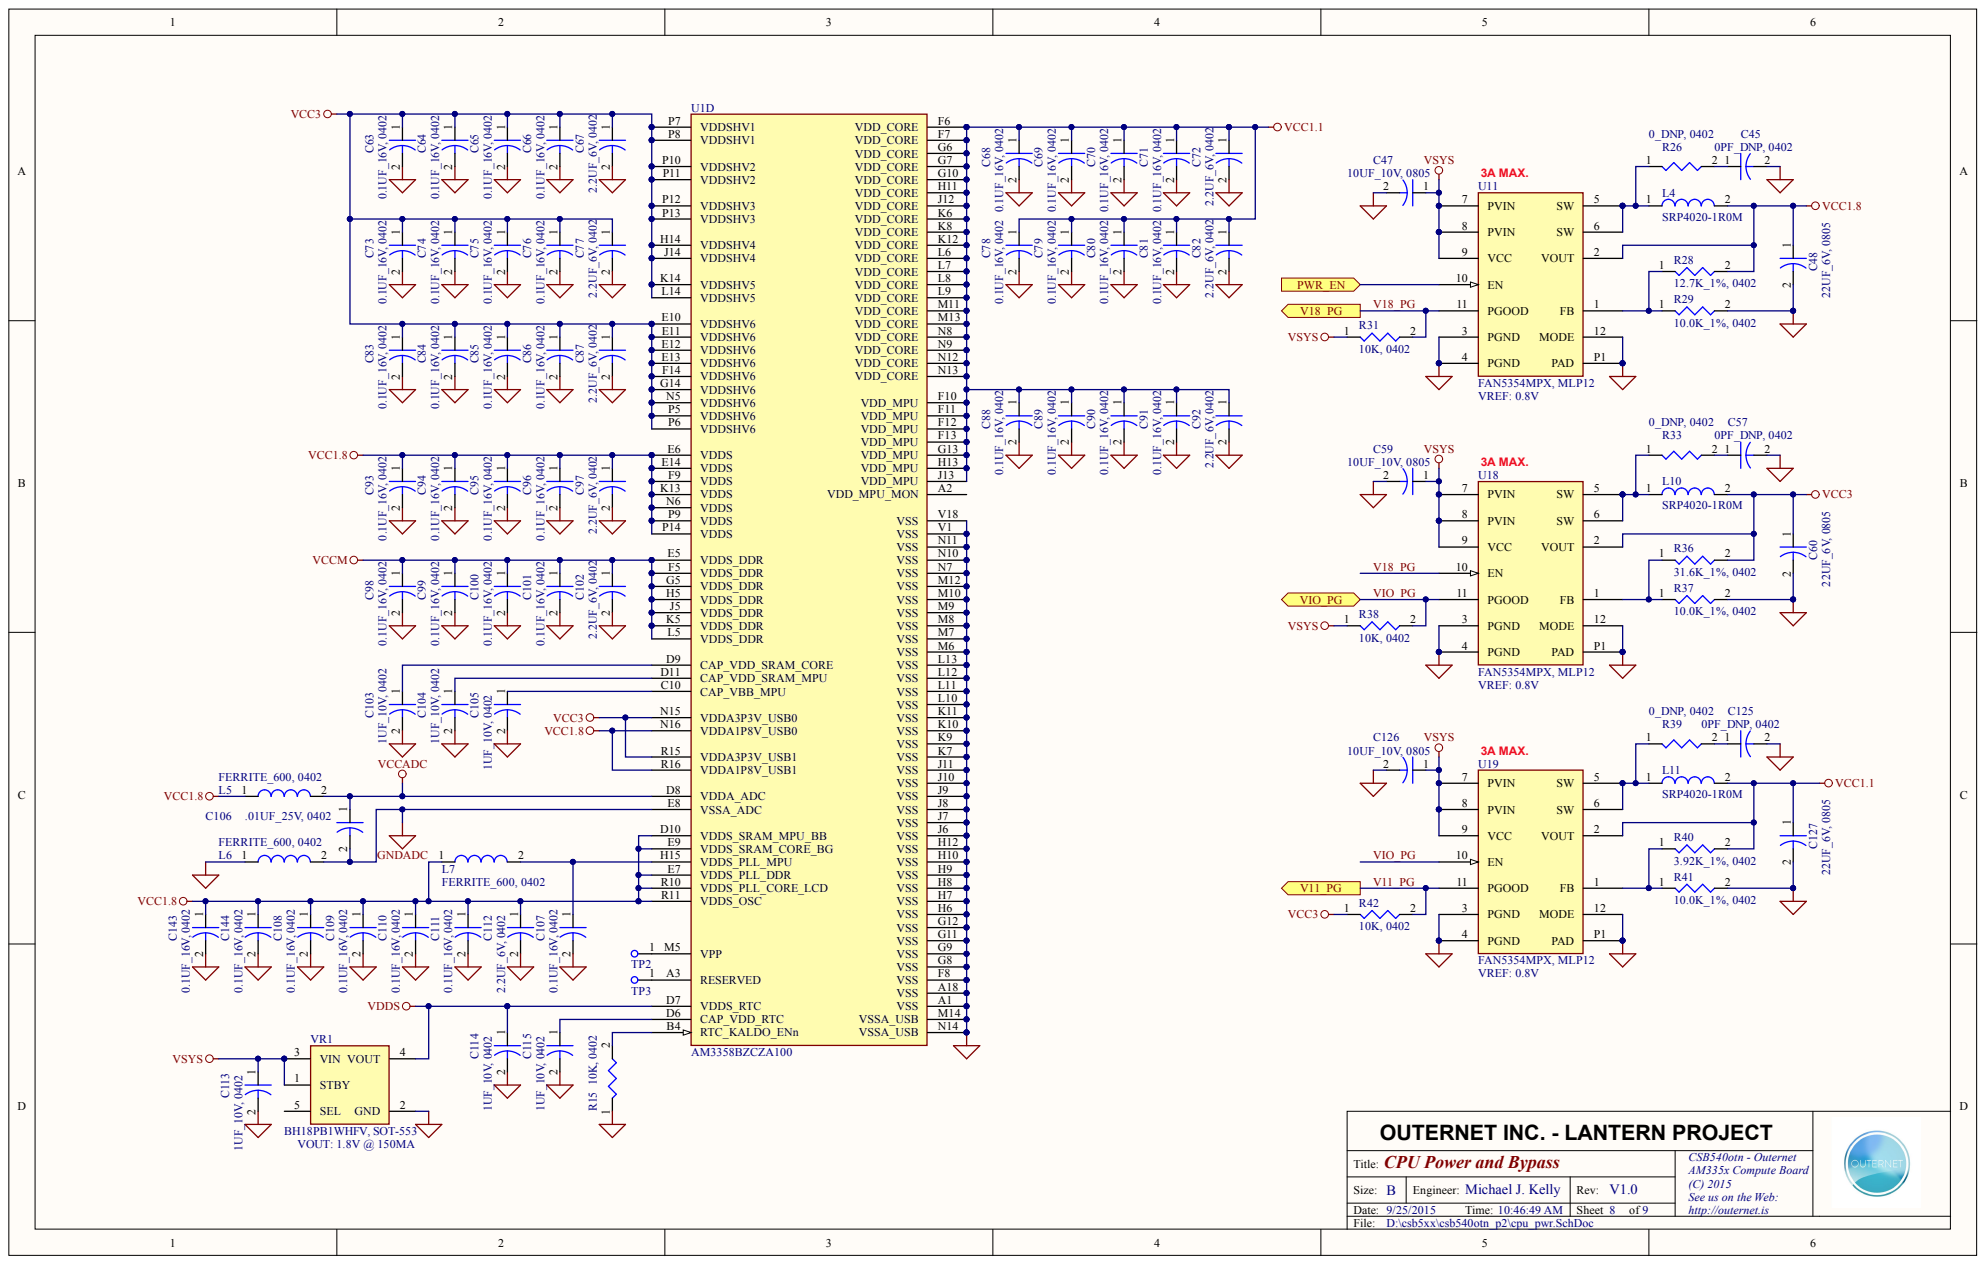
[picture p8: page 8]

VDDSHV6 E13 | 2
VDDSHV6 F14 | 3
VDDSHV6 G14 | 0 | FAN5 3 5 4MPX, MLP1

VDDSHV6 P5 | 1
VDDSHV6 P6 | 2
VDDS E6 | 3

VDDS_DDR G5 | 2
VDDS_DDR H5 | 0

OUTERNET INC. - LANTERN PROJECT

Title: CPU Power and Bypass | CSB5 4 0 otn - Outernet AM3 3 5x Comp ute Bo a rd (C) 2 0 1 5 See us o n the Web : http://o uternet.is

Size: B | En gineer: Michael J. Kelly | Rev : V1.0

Date: 9/2 5/2 0 1 5 Time: 1 0:4 6:4 9 AM | | Sheet 8 o f 9

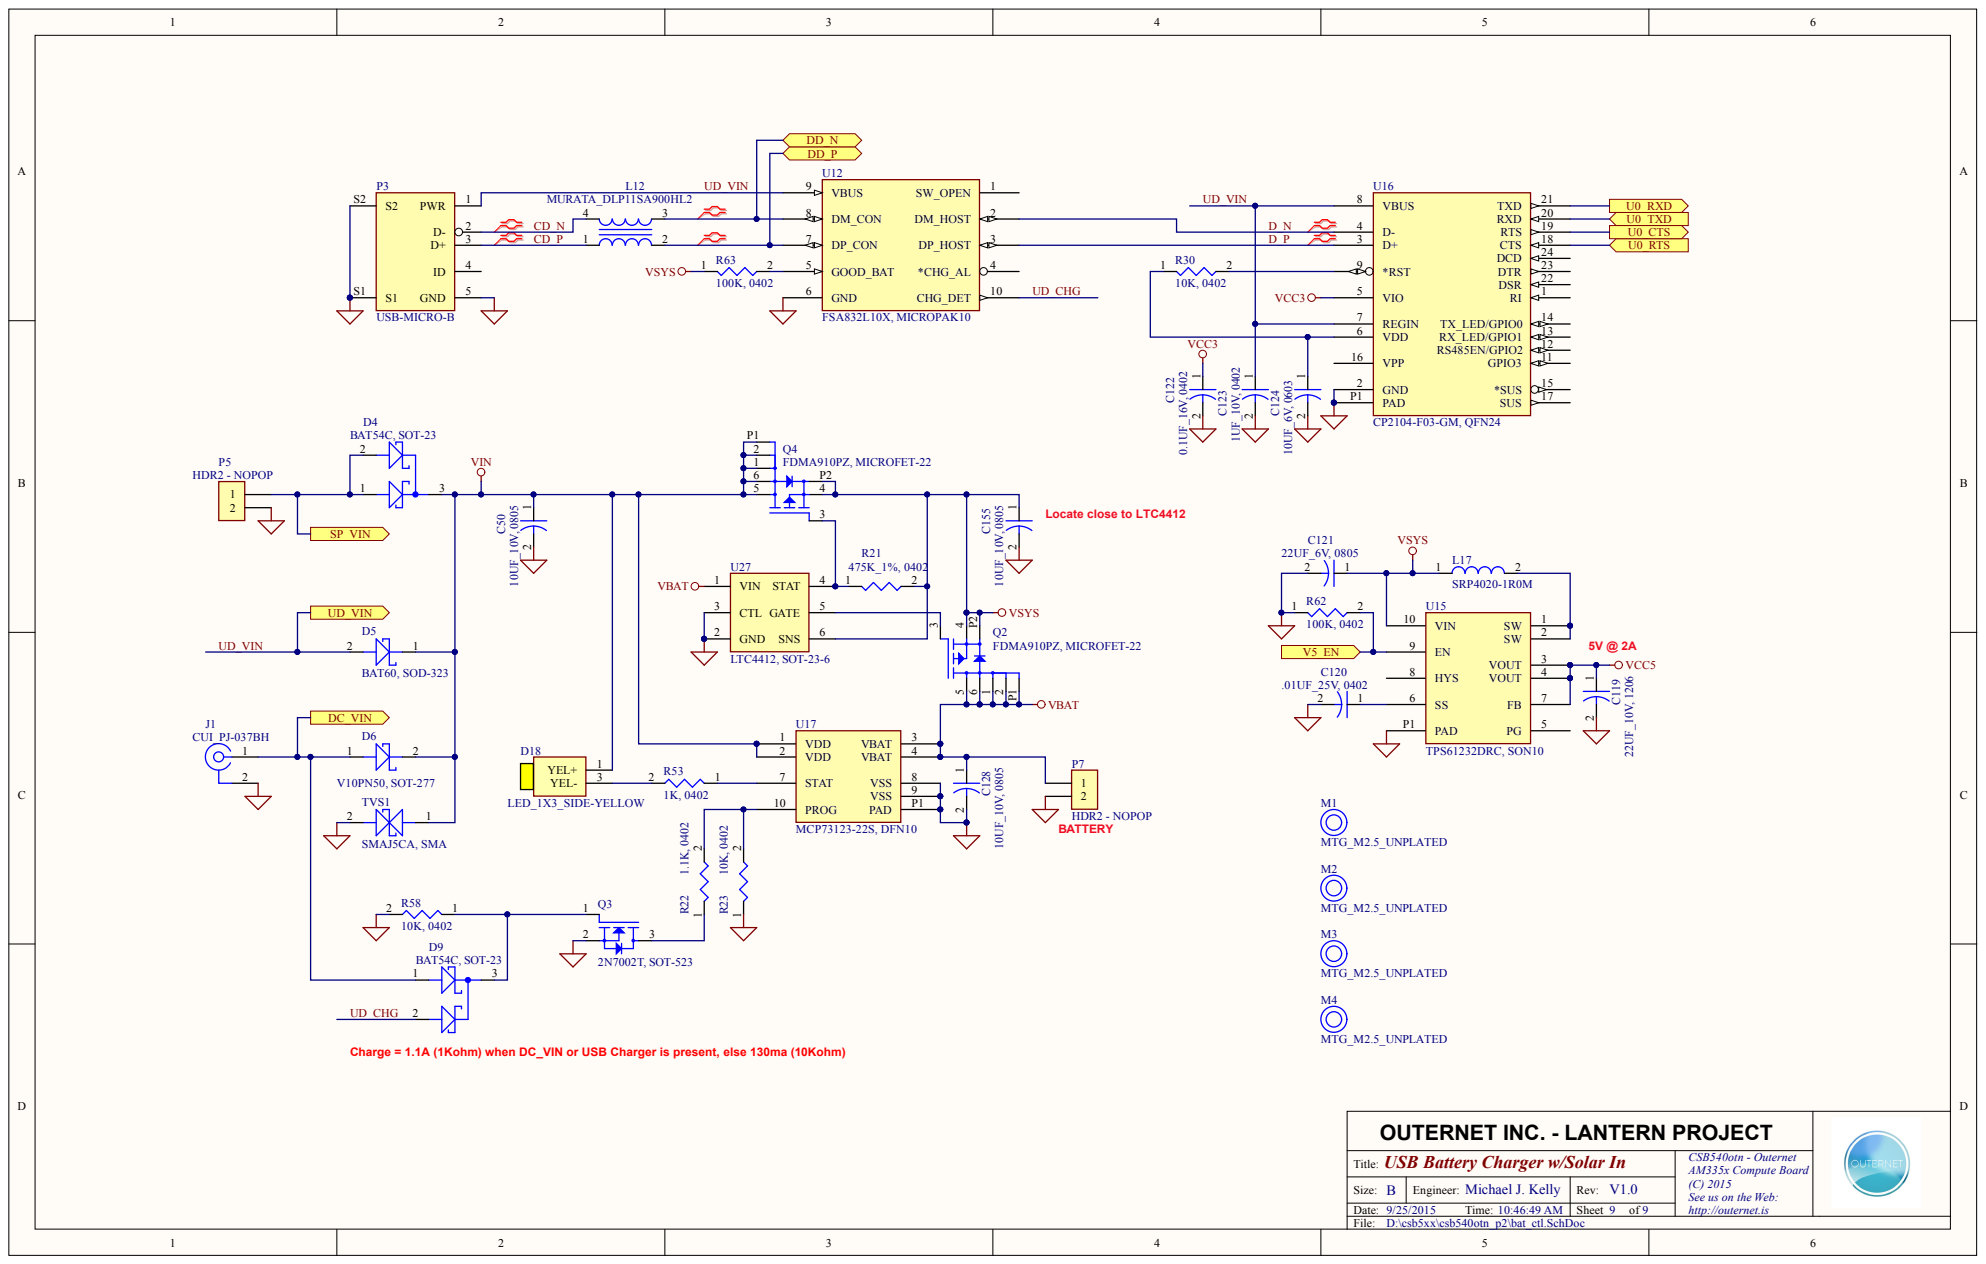
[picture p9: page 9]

Charge = 1.1A (1Kohm) when DC_VIN or USB Charger is present, else 130ma (10Kohm)

OUTERNET INC. - LANTERN PROJECT

Title: USB Battery Charger w/Solar In | CSB540otn - Outernet AM335x Compute Board (C) 2015 See us on the Web: http://outernet.is

Size: B | Engineer: Michael J. Kelly | Rev: V1.0

Date: 9/25/2015 Time: 10:46:49 AM | | Sheet 9 of 9

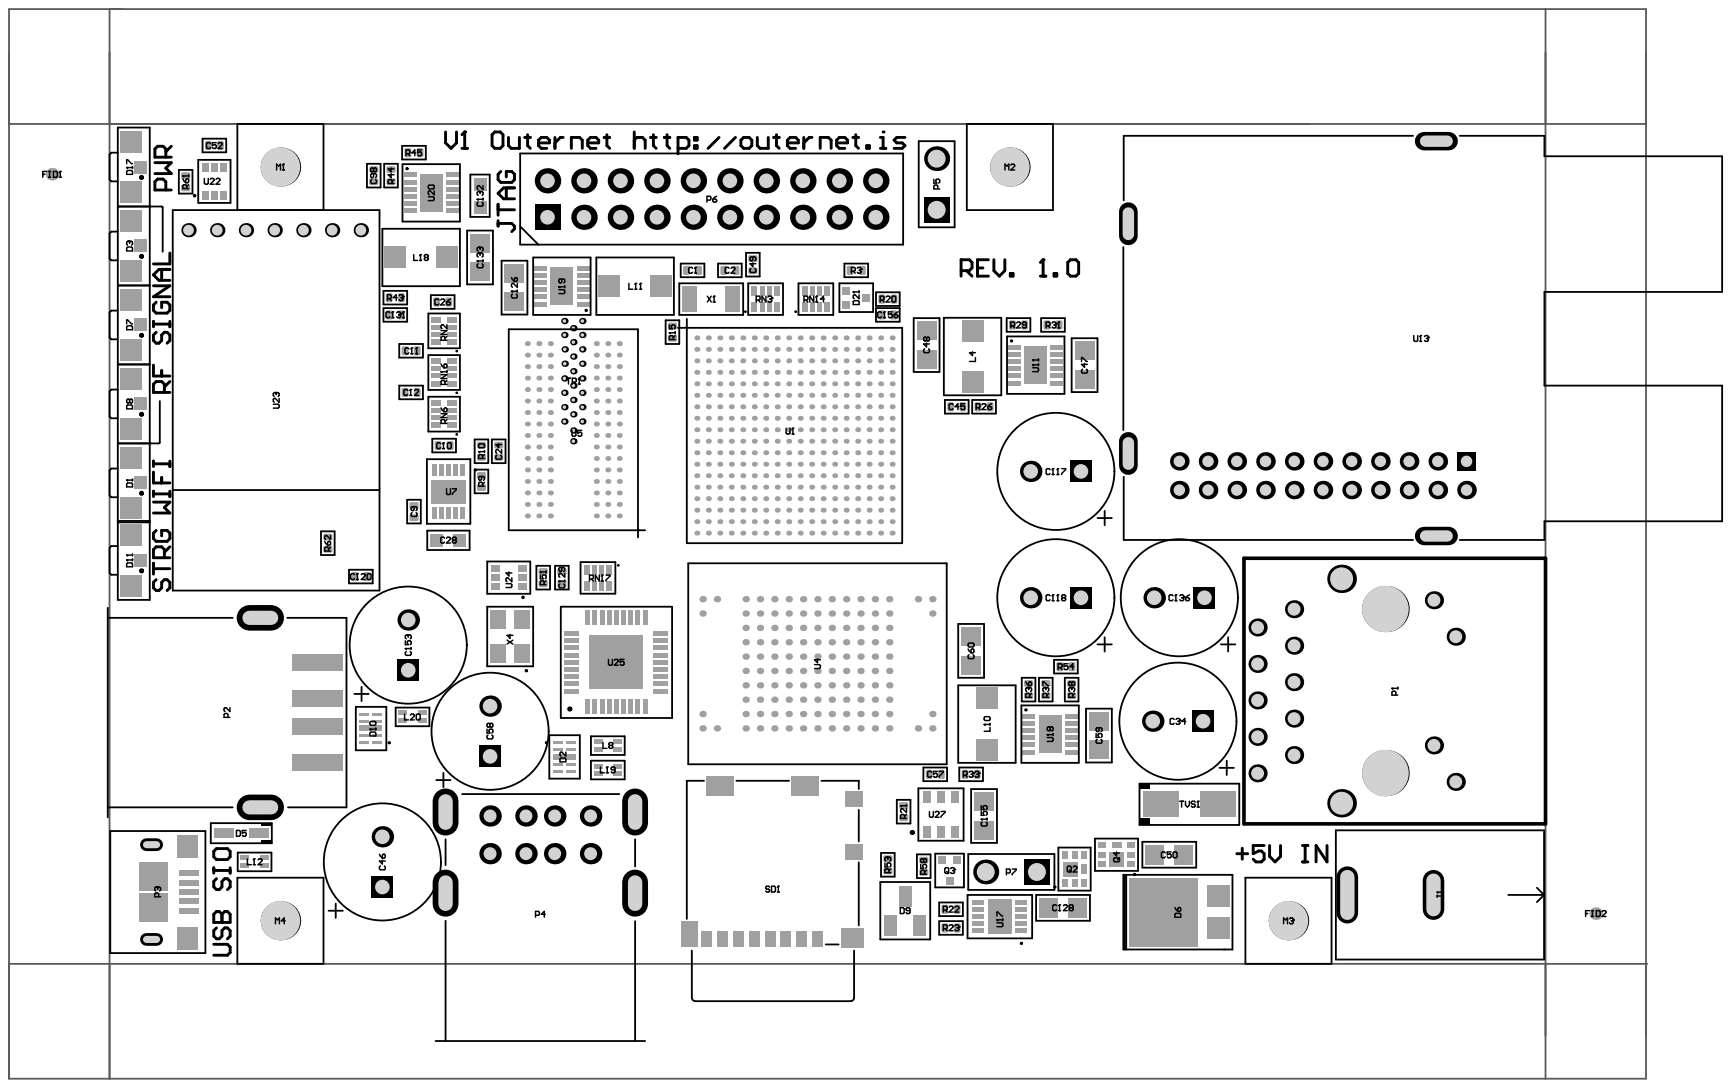
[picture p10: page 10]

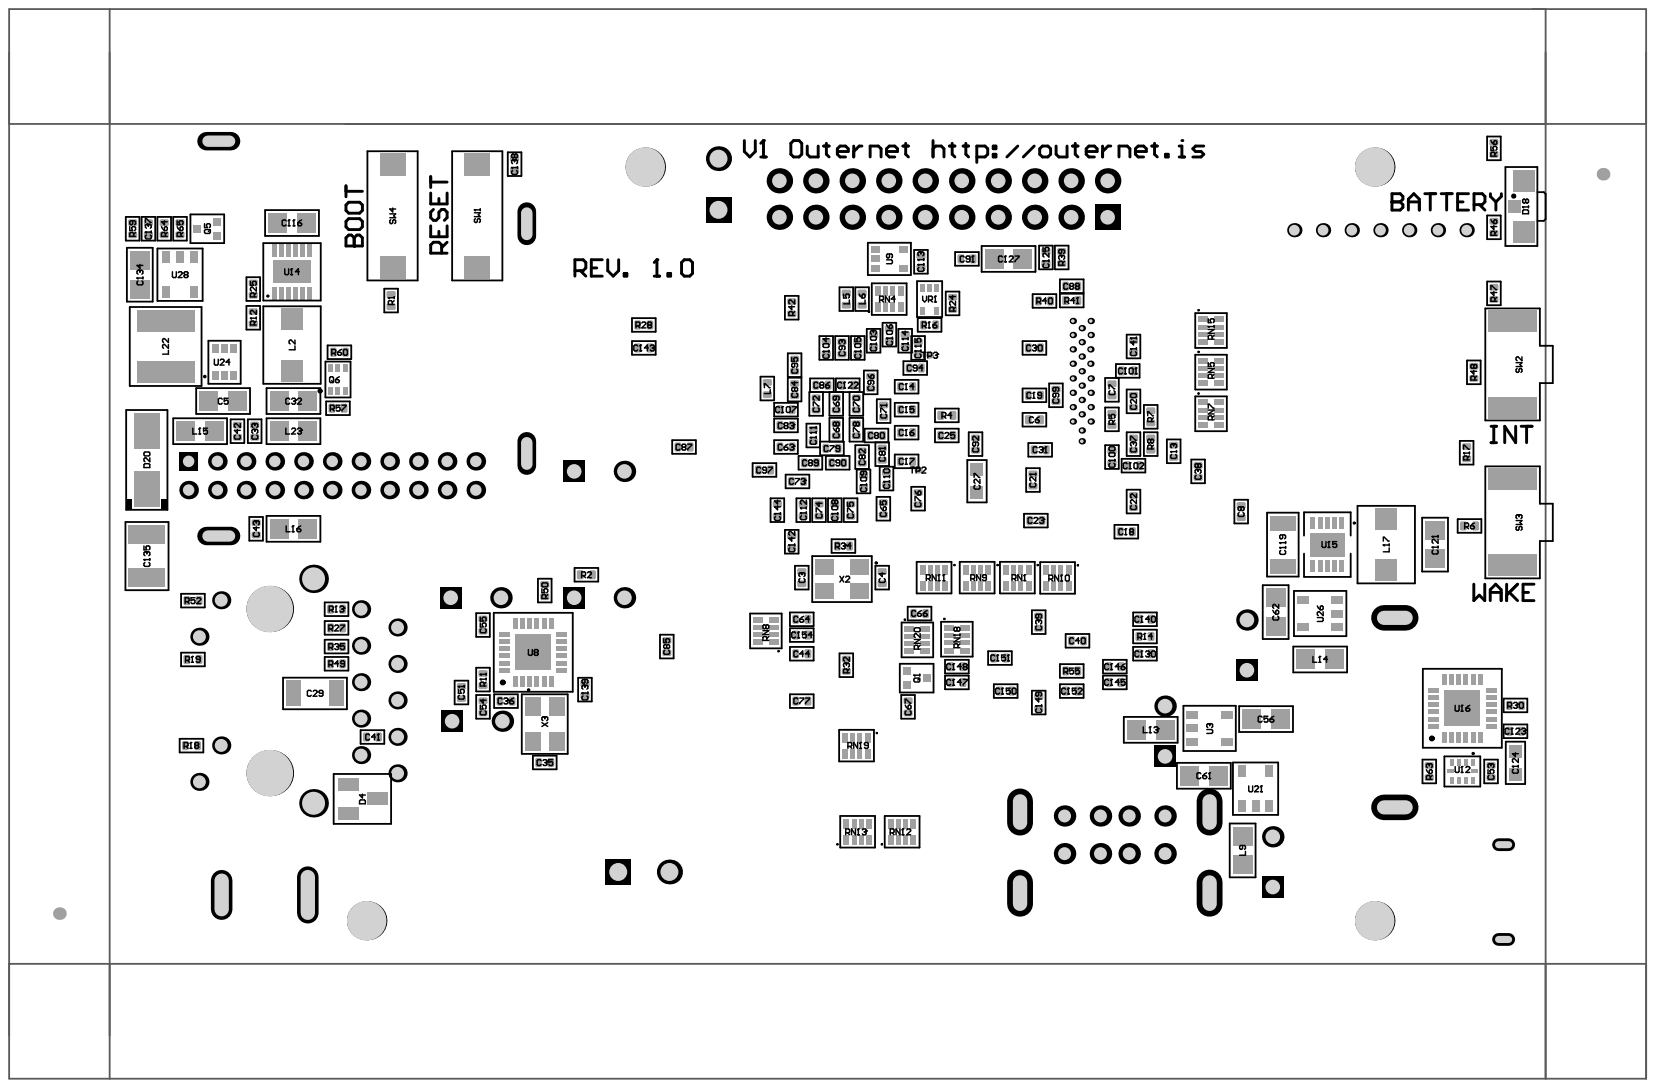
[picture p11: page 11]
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

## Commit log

2015-09-25 Added all hardware project files
    [CSB540otn.GBL, CSB540otn.GBO, CSB540otn.GBP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]
2015-09-28 Swapped BOM
    Added BOM with manufacturer names and part numbers
    [CSB540otn_bom_v1.0.xlsx, CSB540otn_bom_v1.0_VENDORS.xlsx]
